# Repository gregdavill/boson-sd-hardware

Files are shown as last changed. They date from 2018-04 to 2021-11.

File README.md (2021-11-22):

# bosonFrameGrabber

	Project Stage: Basic MVP achieved

A Small FPGA based board. Designed to connect to a FLIR Boson Camera, and save images from the camera to a microSD card.

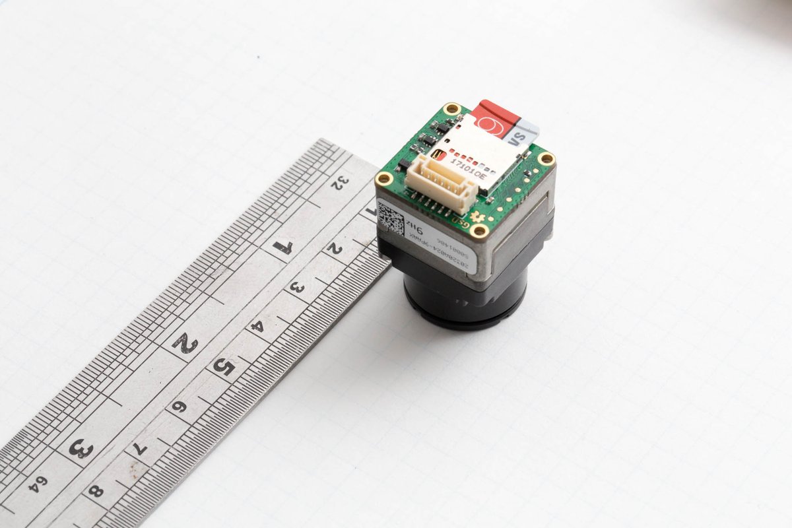
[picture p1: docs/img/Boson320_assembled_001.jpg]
Assembled Prototype

hw 1_02 is the latest functionaly hardware that fits just behind the back of the Boson. (Pictured Above)

## Project Status:
 + hw 1_01 working (reached limitations of FPGA)
 + hw 1_02 status
   + designed/assembled prototypes
   + Working on Firmware on a softcore riscv CPU. 
   + Basic capture system implmented in rtl.
   + Basic driver for SD card access using FatFS and SD-controller.

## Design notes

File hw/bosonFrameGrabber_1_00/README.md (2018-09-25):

# bosonFrameGrabber v1.00

	Board Status: Discarded
	Note: bad footprint for HyperRam.

A Small FPGA based board. Designed to connect to a FLIR Boson Camera, and save images from the camera to a microSD card.

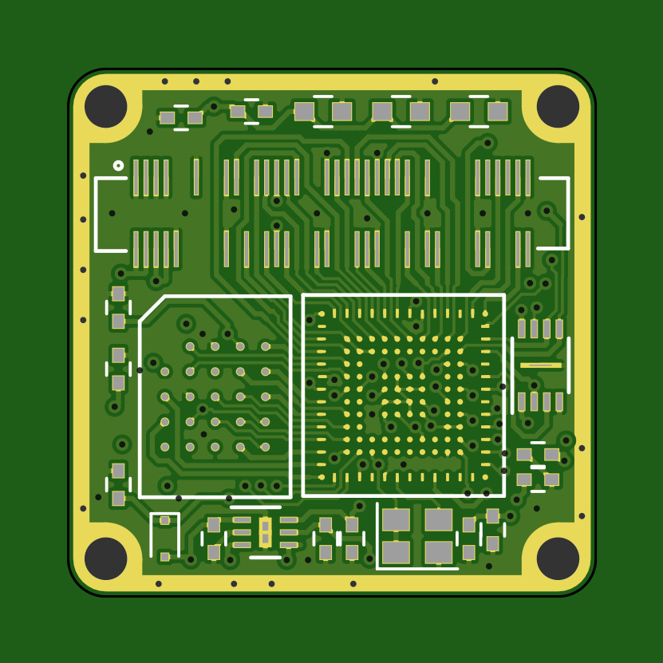
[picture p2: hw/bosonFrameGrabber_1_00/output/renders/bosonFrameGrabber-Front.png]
bosonFrameGrabber Front

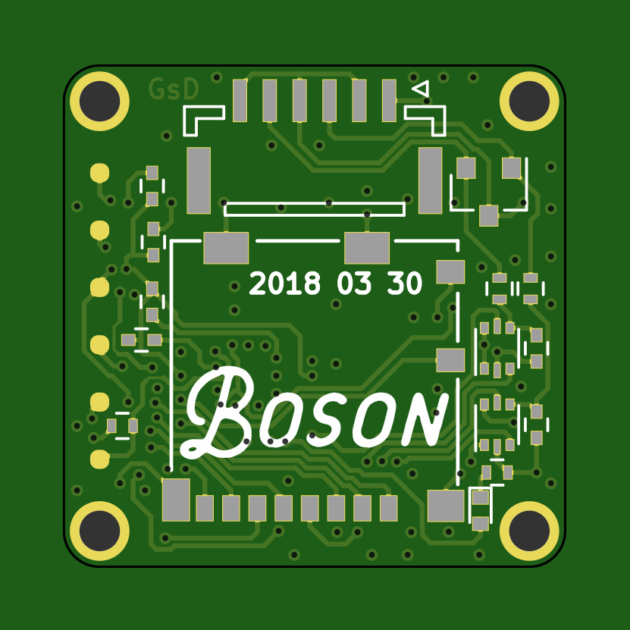
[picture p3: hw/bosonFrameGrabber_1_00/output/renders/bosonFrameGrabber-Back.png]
bosonFrameGrabber Back


## Hardware

* ICE40HX8K in csBGA132 package
* HyperRAM: high density, but low pin count.
* QSPI Memory
* MicroSD socket
* MEMs Oscillator
* JST GH SM06 locking Data/Power connector
* JTAG exposed via pogo pin pads.
* 2x 5V tolerant I/Os on connector
* 1x LED!

Prototype Limitations:
* Not quite enough decoupling, not too close to BGA pads.
* 3.3V only! (Integrated LDOs handle FPGA rails, but input power is connected directly to the Boson)
* Non-ideal BGA footprint to reduce prototyping costs.

## Goals

I have not worked with FPGAs in a project before, This project is a toy project of mine, to learn while having a clear goal. 

* Use Icestorm toolchain to develop for FPGA
* Deploy a risc-V softcore into the HX8K.
* Develop a HyperRAM interface.
* Develop/Integrate SDMMC IP. (Intially SD in SPI mode)
* Save Images from the CMOS camera interface to the SD card.

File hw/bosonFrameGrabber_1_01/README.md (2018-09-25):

# bosonFrameGrabber v1.01

	Board Status: Discarded
	Functionally this board worked, but the FPGA lacked the resources to easily enable a true SD mode interface.

A Small FPGA based board. Designed to connect to a FLIR Boson Camera, and save images from the camera to a microSD card.

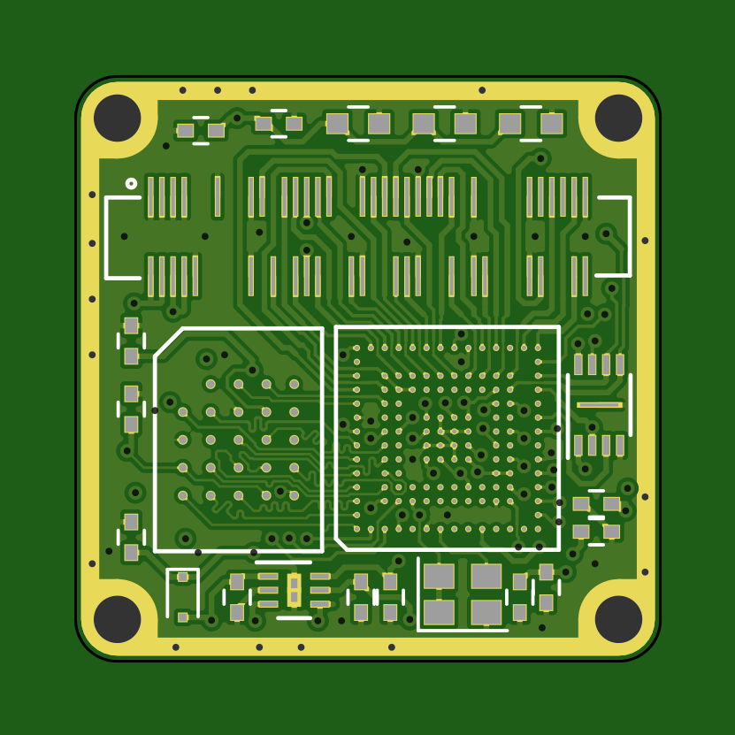
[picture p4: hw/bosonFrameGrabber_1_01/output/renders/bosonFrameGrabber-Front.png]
bosonFrameGrabber Front

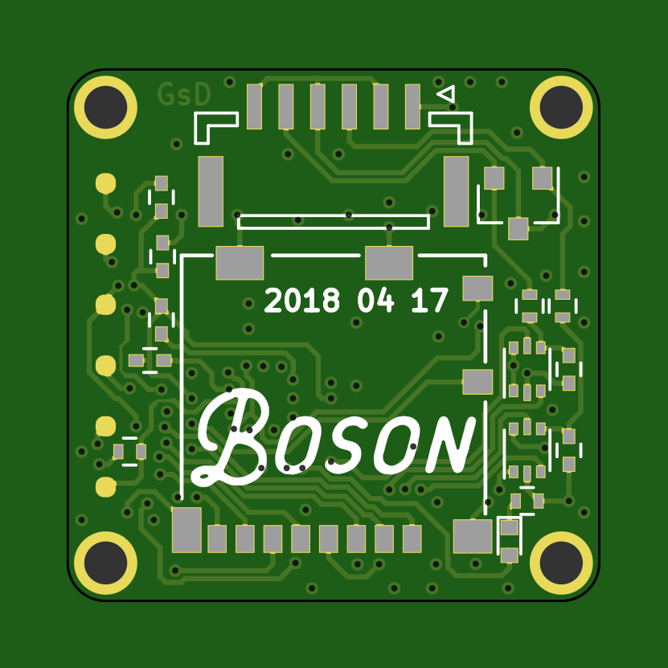
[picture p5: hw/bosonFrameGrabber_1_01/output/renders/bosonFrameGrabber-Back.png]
bosonFrameGrabber Back


## Hardware

* ICE40HX8K in csBGA132 package
* HyperRAM: high density, but low pin count.
* QSPI FLASH Memory
* MicroSD socket
* MEMs Oscillator
* JST GH SM06 locking Data/Power connector
* JTAG exposed via pogo pin pads.
* 2x 5V tolerant I/Os on connector
* 1x LED!

Prototype Limitations:
* Not quite enough decoupling, not too close to BGA pads.
* 3.3V only! (Integrated LDOs handle FPGA rails, but input power is connected directly to the Boson)

## Changes from 1_00
* Updated BGA footprint. Requires 3.5/3.5 (mil) track/space.
* Update HyperRam footprint to match datasheet.
* Length Match HyperRam Bus signals.

## Goals

I have not worked with FPGAs in a project before, This project is a toy project of mine, to learn while having a clear goal. 

* Use Icestorm toolchain to develop for FPGA
* Deploy a risc-V softcore into the HX8K.
* Develop a HyperRAM interface.
* Develop/Integrate SDMMC IP. (Intially SD in SPI mode)
* Save Images from the CMOS camera interface to the SD card.

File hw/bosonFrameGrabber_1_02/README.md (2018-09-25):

# bosonFrameGrabber v1.02

	Project Stage: Still in Development

A Small FPGA based board. Designed to connect to a FLIR Boson Camera, and save images from the camera to a microSD card.

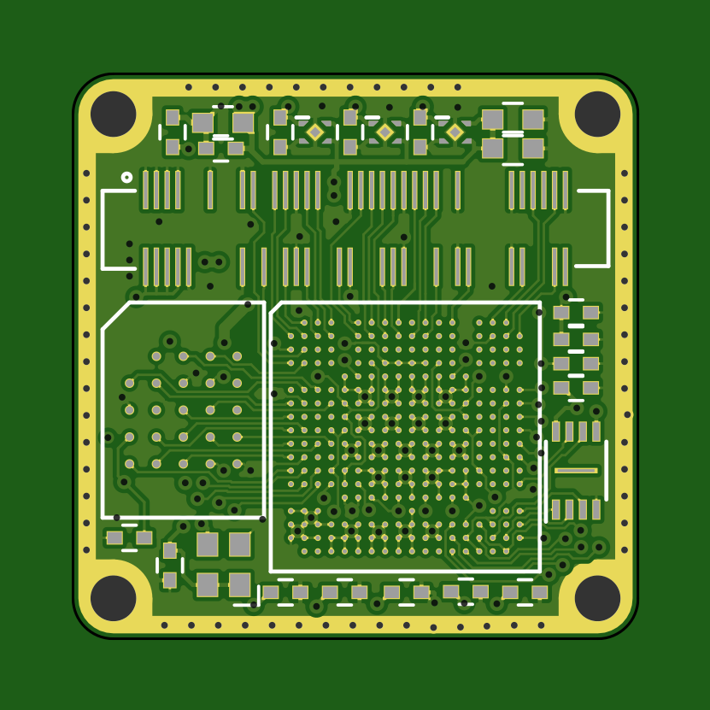
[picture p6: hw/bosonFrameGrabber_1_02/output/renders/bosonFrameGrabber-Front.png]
bosonFrameGrabber Front

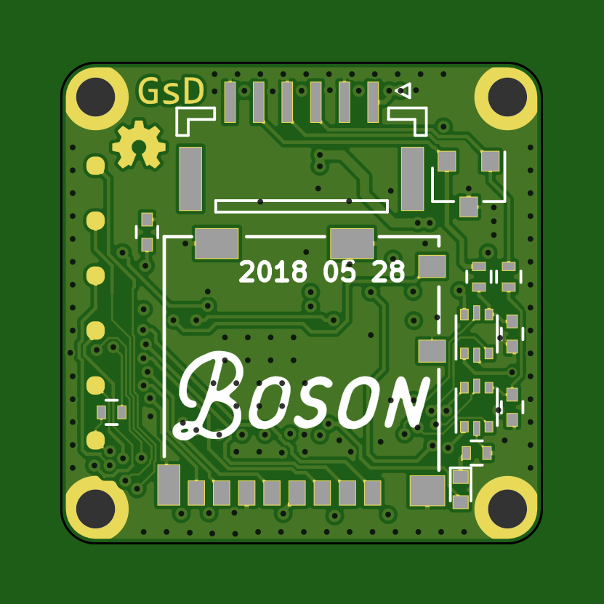
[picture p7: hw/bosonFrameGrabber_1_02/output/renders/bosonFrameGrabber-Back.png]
bosonFrameGrabber Back


## Hardware

* ECP5 in csBGA285 package
* 64Mb/128Mb HyperRAM
* 8Mb QSPI Memory
* MicroSD socket
* 24Mhz MEMs Oscillator
* JST GH SM06 locking Data/Power connector
* JTAG exposed via pogo pin pads.
* 2x 5V tolerant I/Os on connector
* 1x LED

Prototype Limitations:
* 3.3V only! (Integrated LDOs handle FPGA rails, but input power is connected directly to the Boson)

## Prototype

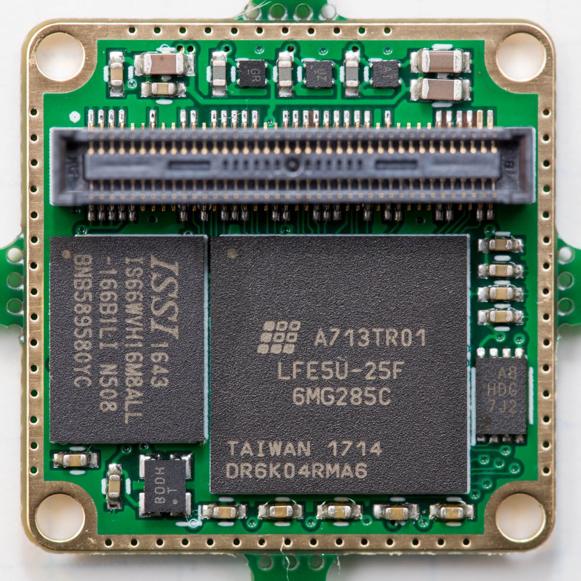
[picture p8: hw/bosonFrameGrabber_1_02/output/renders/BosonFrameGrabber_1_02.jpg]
bosonFrameGrabber Proto


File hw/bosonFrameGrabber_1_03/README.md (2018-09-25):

# bosonFrameGrabber 1_03

	Development BigBoard (Do not use! known errata)

Due to supply issues of the ECP5 in cs285 I developed this PCB to start work on firmware. Despite many errata the board was functional (after mods) and did aid in fw development.

## Errata
* 1V8 line shorted by a via (didn't run DRC)
* SysConfig pins are not correct for loading bitstream from SPI.
* Incorrect pins connected to QSPI.
* 3V3 not connected to backlinght DCDC

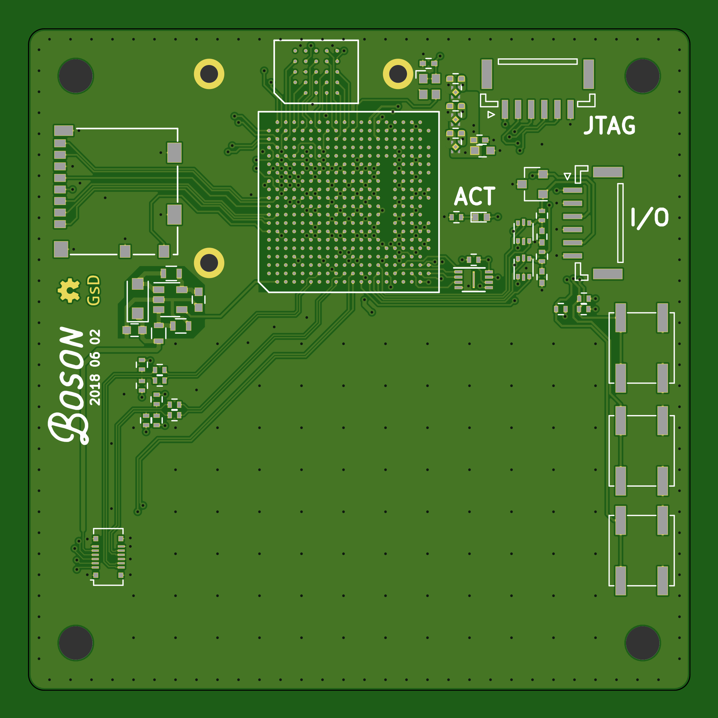
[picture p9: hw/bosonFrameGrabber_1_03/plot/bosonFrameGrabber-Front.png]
bosonFrameGrabber Front

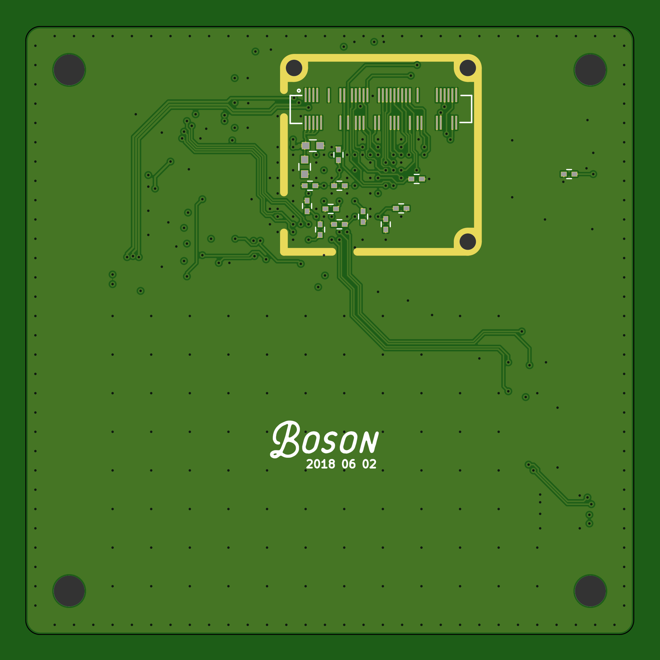
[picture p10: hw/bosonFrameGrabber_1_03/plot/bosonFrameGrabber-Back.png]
bosonFrameGrabber Back


## Hardware

* ECP5 
* 8MB/16MB HyperRAM: high density, low pin count.
* 1MB QSPI Memory (XSON 3x2 package)
* MicroSD socket
* MEMs Oscillator
* JST GH SM06 locking Data/Power connector
* JTAG on GH SM06
* 2x 5V tolerant I/Os on connector
* 1x LED
* 240x240 IPS LCD. (used on NANO v6, MIPI interface)

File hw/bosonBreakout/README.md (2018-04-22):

# bosonBreakout

	Project Stage: VERY Early Development
	!!! Note this design has an incorrect HyperRam footprint !!!

(Initially a project called: CrushedICE)

A FPGA based camera interface board. This PCB was developed before the bosonFrameGrabber, and has a vastly different architecture. It uses an ICE5LP4K, HyperRAM and a QSPI bridge to a SAMD51.

FPGA+RAM will act as a FIFO, connect to SAMD51 via QSPI. To read out a frame when required. SAMD51 has a SDMMC module so it handles the writing to an SD card. 

Filled with test headers to make it easy to connect to a Saleae Logic analyser.

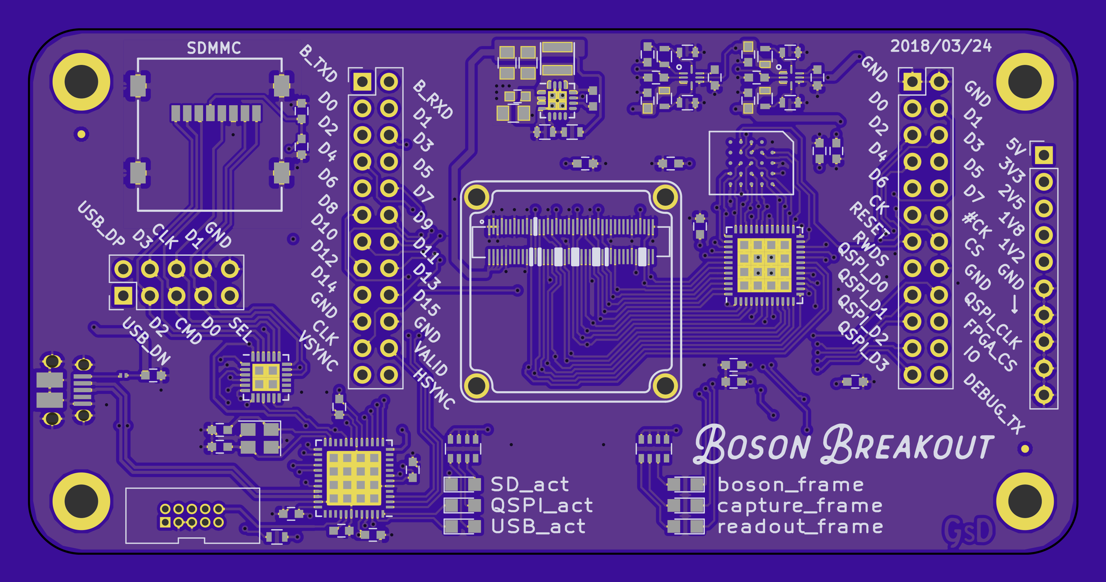
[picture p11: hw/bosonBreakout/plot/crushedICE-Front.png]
bosonFrameGrabber Front

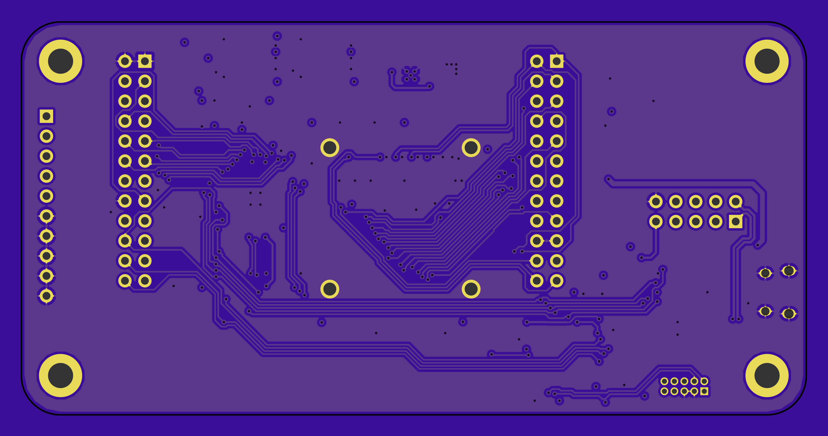
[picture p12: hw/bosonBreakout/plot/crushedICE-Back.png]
bosonFrameGrabber Back


## Hardware

* ICE5LP4K in QFN48 package
* HyperRAM: high density, but low pin count.
* QSPI Bus
* Microchip SAMD51
* MicroSD socket
* 16MHz Oscillator
* 6x LEDs!
* TOO MANY TEST POINTS!

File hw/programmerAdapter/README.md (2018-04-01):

# programmerAdapter

	Project Stage: Early Development

A simple adapter for Esden's ftdi universial Breakout board. <br>https://github.com/icebreaker-fpga/icebreaker/tree/master/hardware/ftdi-v1.0a 

## Design
Designed to suit the BosonFrameGrabber PCB. This design uses pogoPins to make connection and screws over the mounting holes into the Boson.

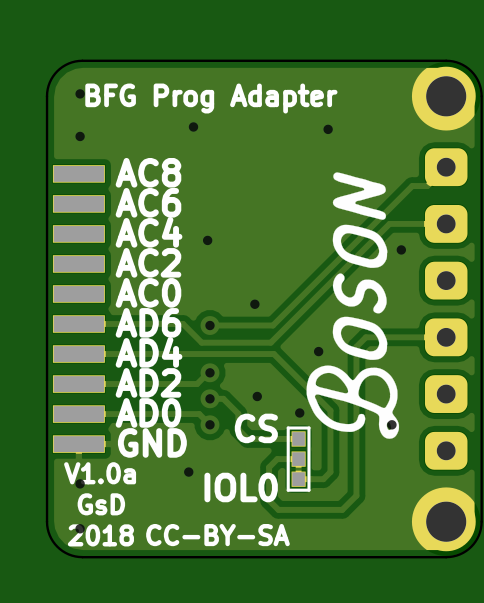
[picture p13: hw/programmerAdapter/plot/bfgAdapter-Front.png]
progammerAdapter Front

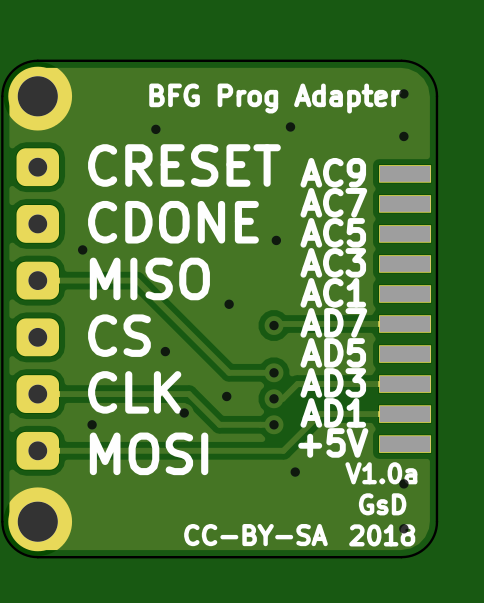
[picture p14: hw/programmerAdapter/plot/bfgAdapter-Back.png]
progammerAdapter Back


## Licence 

To match Esden's work this PCB is licenced: CC-BY-SA

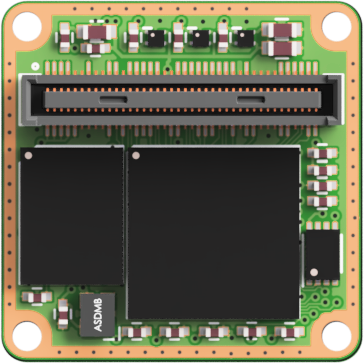
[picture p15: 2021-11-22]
docs/img/boson-r1d2-front.png

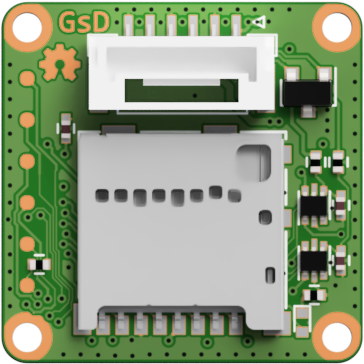
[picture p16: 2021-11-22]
docs/img/boson-r1d2-back.png

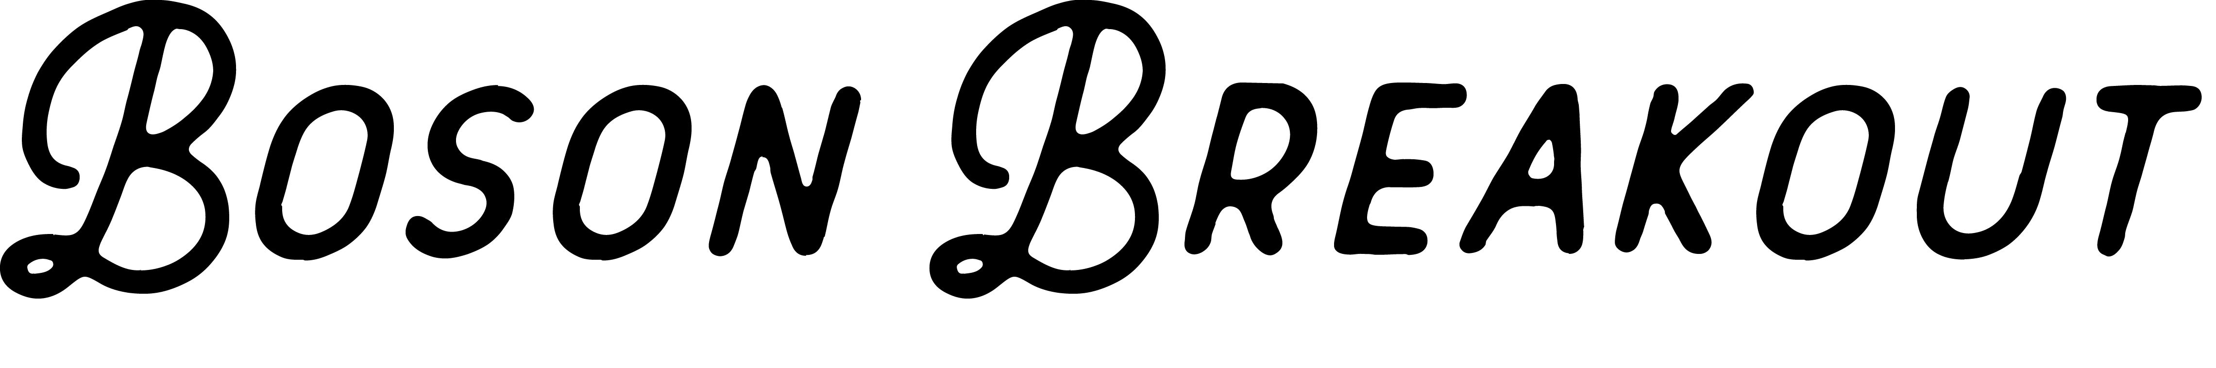
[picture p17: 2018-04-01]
hw/bosonBreakout/Name-01.png

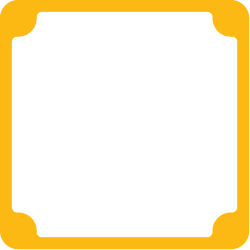
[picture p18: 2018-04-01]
hw/bosonBreakout/3d/boson_footprint.bmp

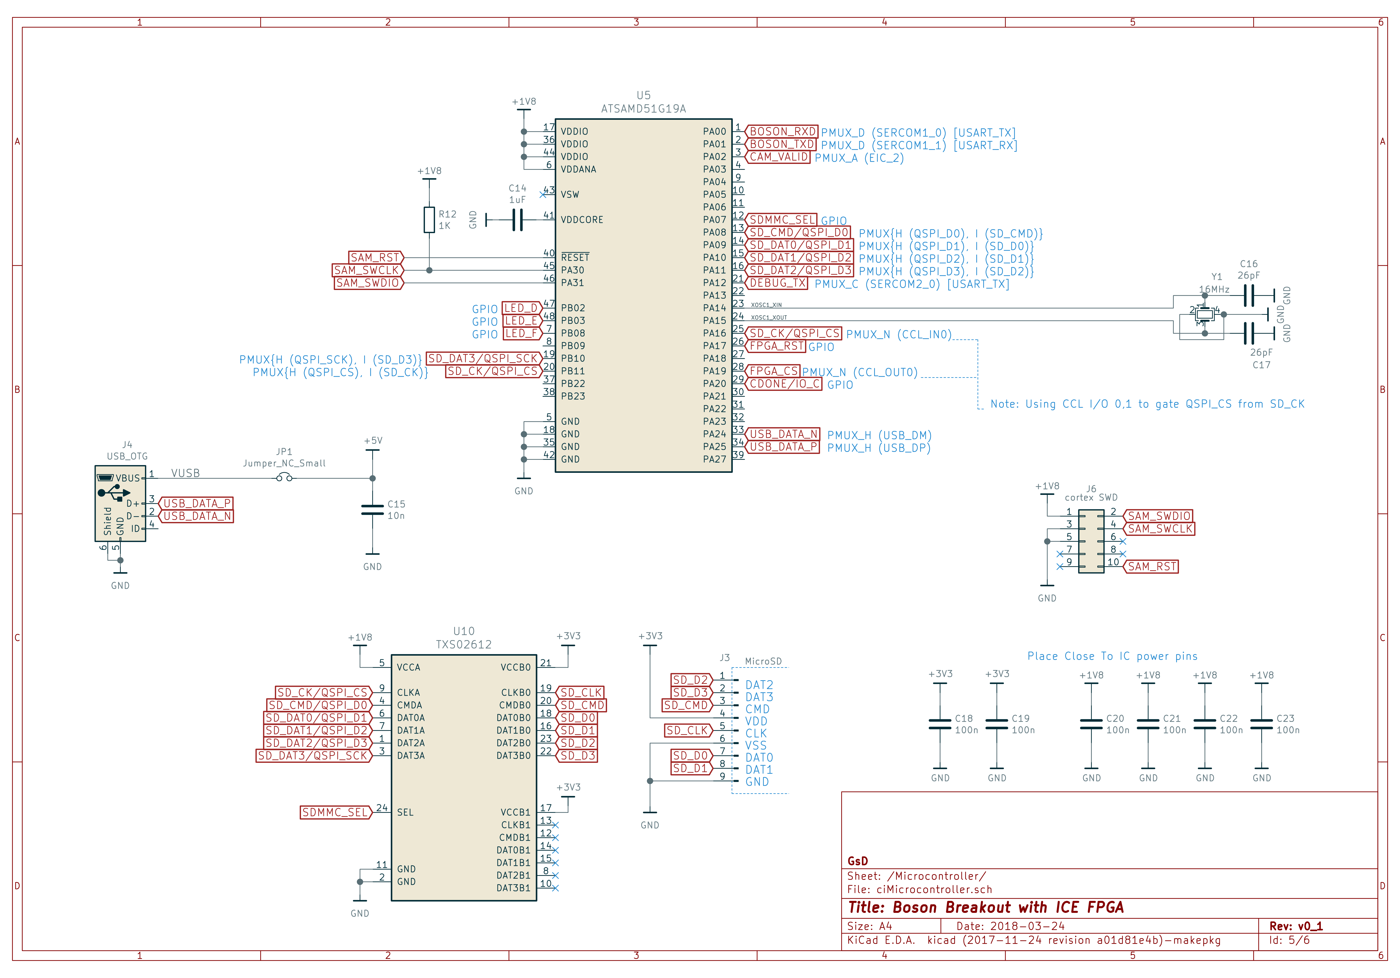
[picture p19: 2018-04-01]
hw/bosonBreakout/plot/ciMicrocontroller-Microcontroller-01.png

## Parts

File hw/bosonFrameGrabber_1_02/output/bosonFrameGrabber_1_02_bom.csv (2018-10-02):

Reference | Quantity | Value | Footprint | Datasheet | PN | SN-DK
C1 C2 | 2 | 100pF | Capacitors_SMD:C_0402 |  | C0402C101J3GACTU | 399-1022-1-ND
C3 C4 C8 | 3 | 1uF | Capacitors_SMD:C_0402 |  | CGB2A1X5R1E105K033BC | 445-13185-1-ND
C10 C11 C12 C14 C15 C16 C17 C18 C19 C20 C21 C22 C5 C9 | 14 | 100nF | Capacitors_SMD:C_0402 |  | CL05B104KP5NNNC | 1276-1002-1-ND
C13 C6 C7 | 3 | 10uF | Capacitors_SMD:C_0603 |  | C1608X5R1A106K080AC | 445-7486-1-ND
D1 | 1 | LED | LEDs:LED_0603 |  | APHHS1005SYCK | 754-1105-1-ND
D2 | 1 | D_TVS_x2_AAC | TO_SOT_Packages_SMD:SOT-23 | https://en.wikipedia.org/wiki/Transient-voltage-suppression_diode | PESD5V0U2BT,215 | 1727-3936-1-ND
J1 | 1 | JST GH Series | Connectors_JST:JST_GH_BM06B-GHS-TBT_06x1.25mm_Straight | ~ | BM06B-GHS-TBT(LF)(SN)(N) | 455-1582-1-ND
J4 | 1 | MicroSD | bosonFrameGrabber:1040310811 | ~ | 1040310811 | WM6357CT-ND
R1 R2 | 2 | 100R | Resistors_SMD:R_0402 |  | RT0402FRE07100RL | YAG3342CT-ND
R3 R4 | 2 | 10k | Resistors_SMD:R_0402 |  | ERA-2AED103X | P10KDECT-ND
U1 | 1 | TLV70725 | bosonFrameGrabber:X2SON |  | TLV70725PDQNT | 296-34993-1-ND
U3 | 1 | ECP5U25 |  |  | LFE5UM-25F-6MG285C | LFE5UM-25F-6MG285C-ND
U4 | 1 | S27KS0641 | bosonFrameGrabber:BGA_24 |  | S27KS0641DPBHI020 | 428-3858-ND
U5 | 1 | Boson |  |  | DF40HC(4.0)-80DS-0.4V(51) | H11919CT-ND
U6 | 1 | AT25SF081 | Housings_DFN_QFN:DFN-8-1EP_3x2mm_Pitch0.5mm |  | AT25SF081-MAHD-T | 1265-1275-1-ND
U2 U7 | 2 | SN74LVC1T45 | TO_SOT_Packages_SMD:SOT-666 |  | SN74LVC1T45DRLR | 296-20629-1-ND
U8 | 1 | TLV71718 | bosonFrameGrabber:X2SON |  | TLV71718PDQNR | 296-36775-1-ND
U9 | 1 | TLV73311 | bosonFrameGrabber:X2SON |  | TLV73311PDQNT | 296-38619-1-ND
X1 | 1 | ASDMB | Oscillators:Oscillator_SMD_SeikoEpson_SG210-4pin_2.5x2.0mm | http://www.abracon.com/Oscillators/ASV.pdf | SIT8008BI-71-18E-24.000000G | 1473-30509-1-ND

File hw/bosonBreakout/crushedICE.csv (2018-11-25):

Reference | Quantity | Value | Footprint | Datasheet | SN-DK | PN | Mfg
C1 | 1 | 10uF | Capacitors_SMD:C_0805 |  | 1276-2402-1-ND
C10 C11 C12 C14 C9 | 5 | 1uF | Capacitors_SMD:C_0603
C15 | 1 | 10n | Capacitors_SMD:C_0603
C16 C17 | 2 | 26pF | Capacitors_SMD:C_0603 |  | 1276-2229-1-ND
C13 C18 C19 C2 C20 C21 C22 C23 C24 C25 C26 C27 C28 C29 C3 C30 C31 | 17 | 100n | Capacitors_SMD:C_0603
C4 C5 C6 | 3 | 22nF | Capacitors_SMD:C_0603 |  | 1276-1104-1-ND
C7 C8 | 2 | 22uF | Capacitors_SMD:C_0805 |  | 490-1719-1-ND
D1 D2 D3 D4 D5 D6 | 6 | led green | LEDs:LED_0805
J1 J2 | 2 | Conn_02x12_Odd_Even
J3 | 1 | MicroSD | lib:SD_holder_472190001 |  | WM6698CT-ND
J4 | 1 | USB_OTG | Connectors:USB_Micro-B_10103594-0001LF |  | 609-4618-1-ND
J5 | 1 | Conn_02x05_Odd_Even | Pin_Headers:Pin_Header_Straight_2x05_Pitch2.54mm
J6 | 1 | cortex SWD | lib:CORTEX_SWD
J7 | 1 | Conn_01x10 | Pin_Headers:Pin_Header_Straight_1x10_Pitch2.54mm
JP1 | 1 | Jumper_NC_Small | Resistors_SMD:R_0201_NoSilk
L1 | 1 | 4.7uH | Inductors:Inductor_Taiyo-Yuden_MD-3030 |  | 490-15977-1-ND | LQH3NPZ4R7MMEL | Murata Electronics North America
R10 | 1 | 23K | Resistors_SMD:R_0603 |  | P23.2KHCT-ND
R12 | 1 | 1K | Resistors_SMD:R_0603
R2 | 1 | 2.0K | Resistors_SMD:R_0603 |  | P2.00KHCT-ND
R4 | 1 | 15K | Resistors_SMD:R_0603 |  | P15.0KHCT-ND
R6 | 1 | 17.8K | Resistors_SMD:R_0603 |  | P17.8KHCT-ND
R11 R3 R5 R7 R9 | 5 | 10K | Resistors_SMD:R_0603 |  | P10.0KHCT-ND
R8 | 1 | 8.0K | Resistors_SMD:R_0603 |  | P8.06KHCT-ND
RN1 RN2 | 2 | R_Pack04 | Resistors_SMD:R_Array_Convex_4x0603
U1 | 1 | ICE5LP4K-SG48 | Housings_DFN_QFN:QFN-48-1EP_7x7mm_Pitch0.5mm |  | 220-2068-1-ND
U10 | 1 | TXS02612 | Housings_DFN_QFN:QFN-24-1EP_4x4mm_Pitch0.5mm |  | 296-23869-1-ND
U2 | 1 | S27KS0641 | lib:BGA_24
U4 | 1 | Boson | lib:DF40_80Pin |  | H11919CT-ND
U5 | 1 | ATSAMD51G19A | Housings_DFN_QFN:QFN-48-1EP_7x7mm_Pitch0.5mm |  | ATSAMD51G19A-MU-ND
U6 U7 | 2 | SC560A | lib:MLPQ-UT8 |  | SC560CULCT-ND
U8 | 1 | TS30011 | Housings_DFN_QFN:QFN-16-1EP_3x3mm_Pitch0.5mm_ThermalVias |  | TS30011-M033QFNRCT-ND | TS30011-M033QFNR | Semtech Corporation
Y1 | 1 | 16MHz | Crystals:Crystal_SMD_3225-4pin_3.2x2.5mm |  | SER4046CT-ND

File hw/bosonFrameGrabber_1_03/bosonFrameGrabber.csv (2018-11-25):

Reference | Quantity | Value | Footprint | Datasheet | SN-DK | PN | Mfg
C1 C2 | 2 | 100pF | Capacitors_SMD:C_0402 |  | 399-1022-1-ND | C0402C101J3GACTU
C23 C24 | 2 | 1uF | Capacitors_SMD:C_0603 |  | 445-12539-1-ND | CGA3E1X7R1C105K080AC
C3 C4 C8 | 3 | 1uF | Capacitors_SMD:C_0402 |  | 445-13185-1-ND | CGB2A1X5R1E105K033BC
C10 C11 C12 C14 C15 C16 C17 C18 C19 C20 C21 C22 C5 C9 | 14 | 100nF | Capacitors_SMD:C_0402 |  | 1276-1002-1-ND | CL05B104KP5NNNC
C13 C6 C7 | 3 | 10uF | Capacitors_SMD:C_0603 |  | 445-7486-1-ND | C1608X5R1A106K080AC
D1 | 1 | LED | LEDs:LED_0603 |  | 754-1105-1-ND | APHHS1005SYCK
D2 | 1 | D_TVS_x2_AAC | TO_SOT_Packages_SMD:SOT-23 | https://en.wikipedia.org/wiki/Transient-voltage-suppression_diode | 1727-3936-1-ND | PESD5V0U2BT,215
D3 | 1 | D_Schottky_ALT | Diodes_SMD:D_SOD-123F |  | 1N5819HW1-7-FDICT-ND
J1 J2 | 2 | JST GH Series | Connectors_JST:JST_GH_BM06B-GHS-TBT_06x1.25mm_Straight |  | 455-1582-1-ND | BM06B-GHS-TBT(LF)(SN)(N)
J4 | 1 | MicroSD | bosonFrameGrabber:1040310811 |  | WM6357CT-ND | 1040310811
J5 | 1 | SlimStack_12P |  |  | WM4662CT-ND | 5035481220
L1 | 1 | L | Inductors_SMD:L_0603 |  | 445-3608-1-ND
R1 R2 | 2 | 100R | Resistors_SMD:R_0402 |  | YAG3342CT-ND | RT0402FRE07100RL
R10 R14 R15 R9 | 4 | 47R | Resistors_SMD:R_0402 |  | YAG3491CT-ND | AC0402FR-0747RL
R11 | 1 | 1K | Resistors_SMD:R_0402 |  | P1.0KJCT-ND | ERJ-2GEJ102X
R12 R13 R7 R8 | 4 | 220R | Resistors_SMD:R_0402 |  | YAG3456CT-ND | AC0402FR-07220RL
R16 R17 R18 R3 R4 | 5 | 10k | Resistors_SMD:R_0402 |  | P10KDECT-ND | ERA-2AED103X
R5 | 1 | 56k | Resistors_SMD:R_0603 |  | RR08P56.0KDCT-ND | RR0816P-563-D
R6 | 1 | 5.1K | Resistors_SMD:R_0603 |  | RR08P5.1KDCT-ND | RR0816P-512-D
SW1 SW2 SW3 | 3 | SW_Push | Buttons_Switches_SMD:SW_SPST_EVQP0 |  | P12244SCT-ND | EVQ-P1K05M
U1 U8 U9 | 3 | TLV733P | bosonFrameGrabber:X2SON |  | 296-38493-1-ND | TLV73325PDQNT | Texas Instruments
U10 | 1 | AP3012 | TO_SOT_Packages_SMD:SOT-23-5 |  | AP3012KTR-E1DICT-ND | AP3012KTR-E1
U3 | 1 | ECP5U25 |  |  | 220-2052-ND | LFE5U-25F-6BG381I | Lattice
U4 | 1 | S27KS0641 | bosonFrameGrabber:BGA_24 |  | 428-3858-ND | S27KS0641DPBHI020
U5 | 1 | Boson |  |  | H11919CT-ND | DF40HC(4.0)-80DS-0.4V(51)
U6 | 1 | AT25SF081 | Housings_DFN_QFN:DFN-8-1EP_3x2mm_Pitch0.5mm |  | 1265-1275-1-ND | AT25SF081-MAHD-T
U2 U7 | 2 | SN74LVC1T45 | TO_SOT_Packages_SMD:SOT-666 |  | 296-20629-1-ND | SN74LVC1T45DRLR | Texas Instruments
X1 | 1 | ASDMB | Oscillators:Oscillator_SMD_SeikoEpson_SG210-4pin_2.5x2.0mm | http://www.abracon.com/Oscillators/ASV.pdf | 1473-30509-1-ND | SIT8008BI-71-18E-24.000000G

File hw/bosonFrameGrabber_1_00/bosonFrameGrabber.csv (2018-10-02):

Reference | Quantity | Value | Footprint | Datasheet | PN | SN-DK | SN-MO
C1 C2 | 2 | 100pF | Capacitors_SMD:C_0402 |  | C0402C101J3GACTU | 399-1022-1-ND
C10 C11 C12 C14 C16 C17 C19 C20 C21 C22 C23 C5 C8 C9 | 14 | 100n | Capacitors_SMD:C_0402 |  | CL05B104KP5NNNC | 1276-1002-1-ND
C3 C4 | 2 | 1uF | Capacitors_SMD:C_0402 |  | CGB2A1X5R1E105K033BC | 445-13185-1-ND
C13 C6 C7 | 3 | 10uF | Capacitors_SMD:C_0603 |  | C1608X5R1A106K080AC | 445-7486-1-ND
D1 | 1 | LED | LEDs:LED_0603 |  | LTST-C191KGKT | 160-1446-1-ND
D2 | 1 | D_TVS_x2_AAC | TO_SOT_Packages_SMD:SOT-23 | https://en.wikipedia.org/wiki/Transient-voltage-suppression_diode | PESD5V0U2BT,215 | 1727-3936-1-ND
D3 | 1 | D_ALT | Diodes_SMD:D_SC-80 |  | 1N4148X-TP | 1N4148XTPMSCT-ND
J1 | 1 | JST GH Series | Connectors_JST:JST_GH_BM06B-GHS-TBT_06x1.25mm_Straight |  | BM05B-GHS-TBT(LF)(SN)(N) | 455-1581-1-ND
J4 | 1 | MicroSD | bosonFrameGrabber:1040310811 |  | 1040310811 | WM6357CT-ND
R1 R2 | 2 | 100R | Resistors_SMD:R_0402 |  | RT0402FRE07100RL | YAG3342CT-ND
R3 | 1 | 470R | Resistors_SMD:R_0402 |  | RMCF0402JT470R | RMCF0402JT470RCT-ND
R4 | 1 | 10k | Resistors_SMD:R_0402 |  | ERA-2AED103X | P10KDECT-ND
U1 | 1 | MIC5370 |  |  | MIC5370-G4YMT-TR | 576-3329-1-ND | 998-MIC5370-G4YMTTR
U3 | 1 | ICE40HX8K-CB132 | bosonFrameGrabber:csBGA_132 |  | ICE40HX8K-CB132 | 220-1577-ND
U4 | 1 | S27KS0641 | bosonFrameGrabber:BGA_24 |  | S27KS0641DPBHI020 | 428-3858-ND
U5 | 1 | Boson |  |  | DF40HC(4.0)-80DS-0.4V(51) | H11919CT-ND
U6 | 1 | AT25SF081 | Housings_DFN_QFN:DFN-8-1EP_3x2mm_Pitch0.5mm |  | AT25SF081-MAHD-T | 1265-1275-1-ND
U2 U7 | 2 | SN74LVC1T45 | TO_SOT_Packages_SMD:SOT-666 |  | SN74LVC1T45DRLR | 296-20629-1-ND
X1 | 1 | ASDMB | Oscillators:Oscillator_SMD_SeikoEpson_SG210-4pin_2.5x2.0mm | http://www.abracon.com/Oscillators/ASV.pdf | ASDMB-24.000MHZ-LC-T | 535-11728-1-ND

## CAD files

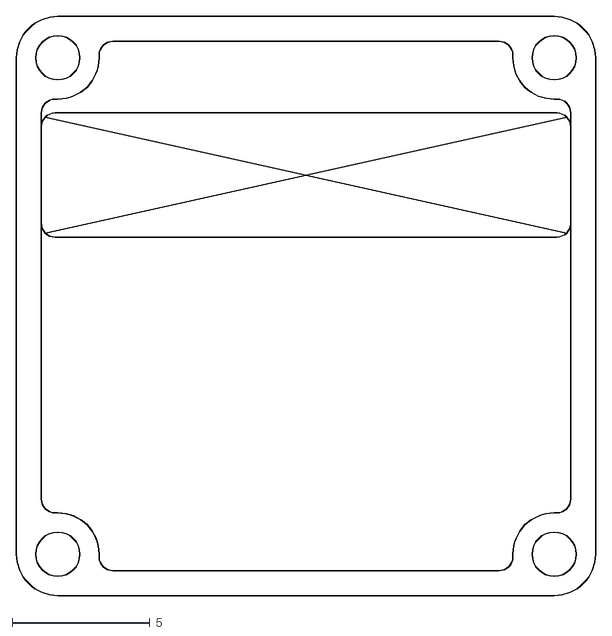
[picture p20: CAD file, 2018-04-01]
hw/bosonBreakout/3d/Boson_frame.dxf
21.0 x 21.0

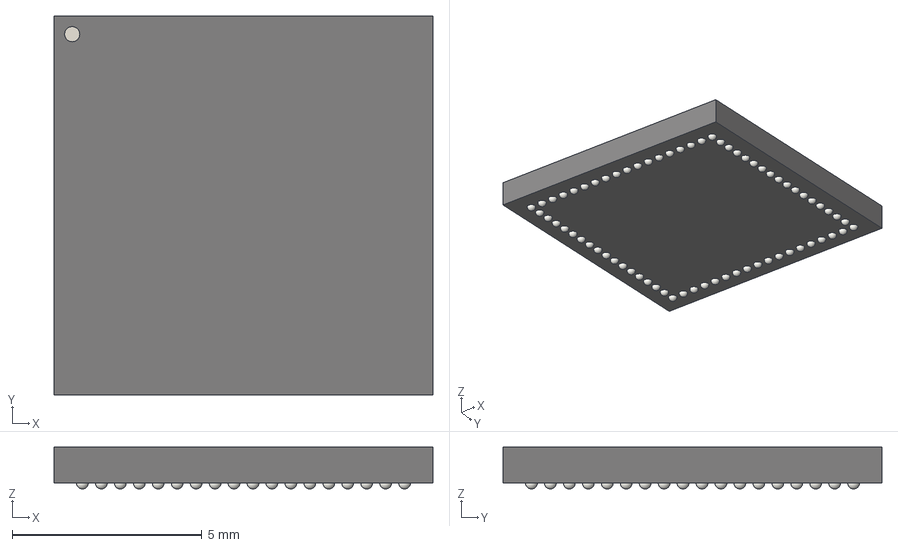
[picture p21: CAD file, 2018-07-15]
hw/bosonFrameGrabber_1_02/3d/csBGA285.step
10.0 x 10.0 x 1.11 mm

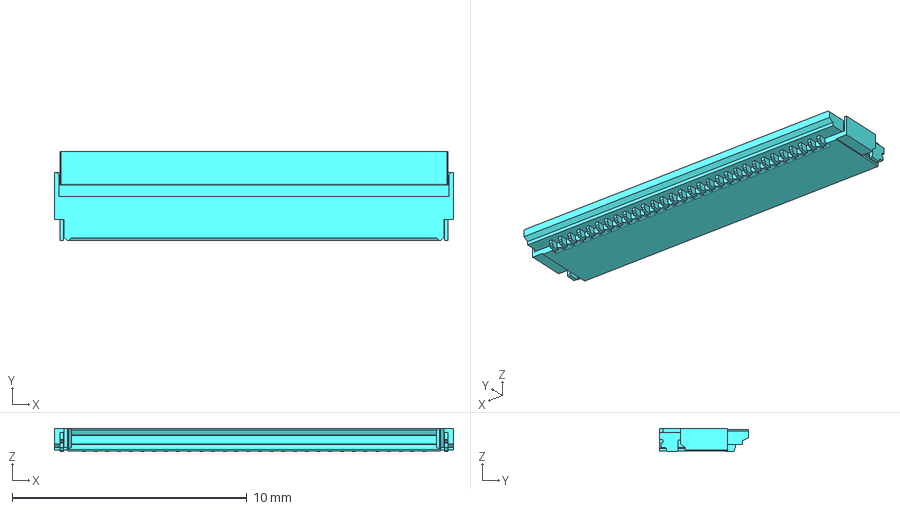
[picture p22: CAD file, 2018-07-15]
hw/bosonFrameGrabber_1_03/3d/FH34SRJ-30S-0.5SH.stp
17.0 x 3.80 x 1.00 mm

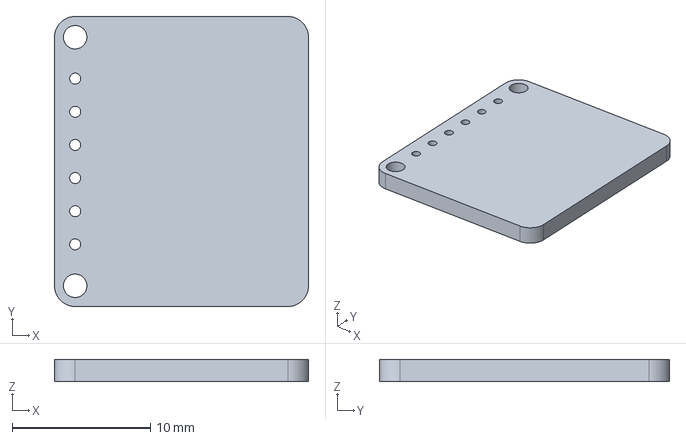
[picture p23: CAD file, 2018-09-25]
hw/programmerAdapter/bfgAdapter.stp
18.4 x 21.0 x 1.60 mm

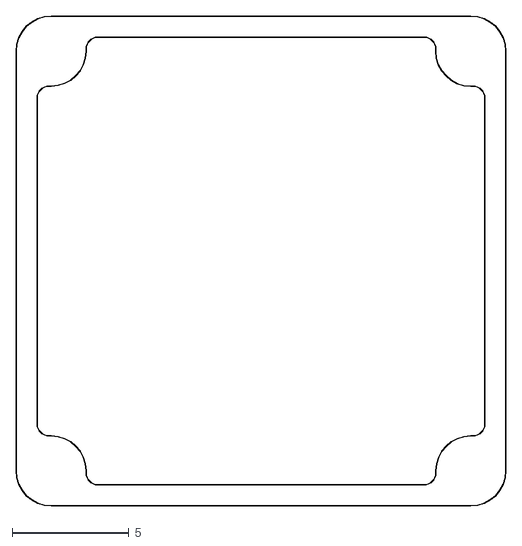
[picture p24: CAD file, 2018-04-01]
hw/bosonBreakout/3d/boson_footprint.dxf
21.0 x 21.0

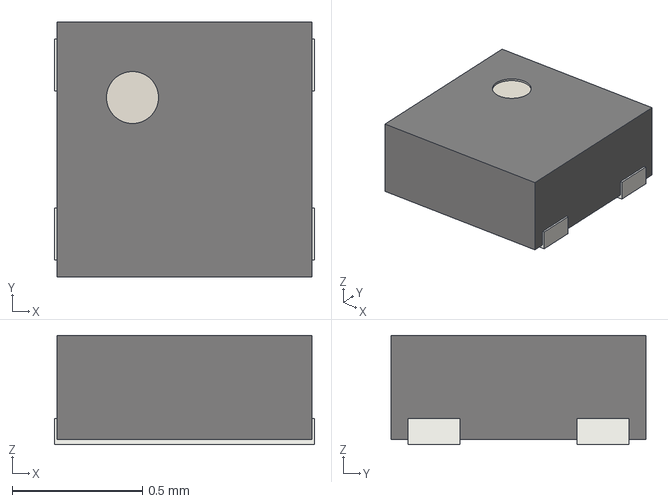
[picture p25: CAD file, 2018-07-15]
hw/bosonFrameGrabber_1_02/3d/xson-4.step
1.00 x 0.98 x 0.42 mm

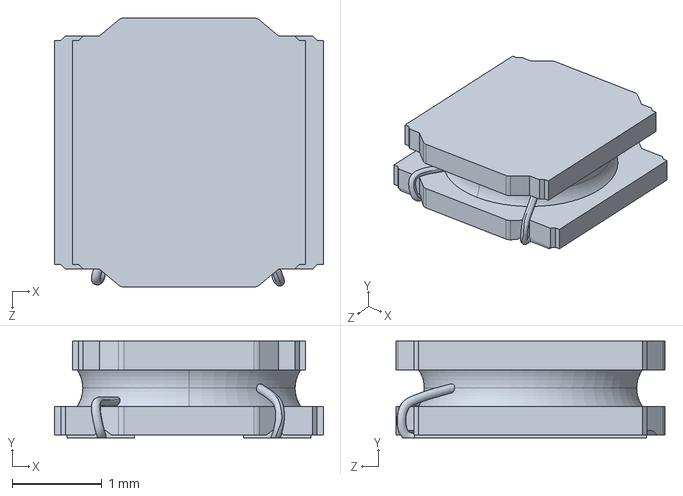
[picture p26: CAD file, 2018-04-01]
hw/bosonBreakout/3d/ASPI-3012S.STEP
3.00 x 1.08 x 3.00 mm

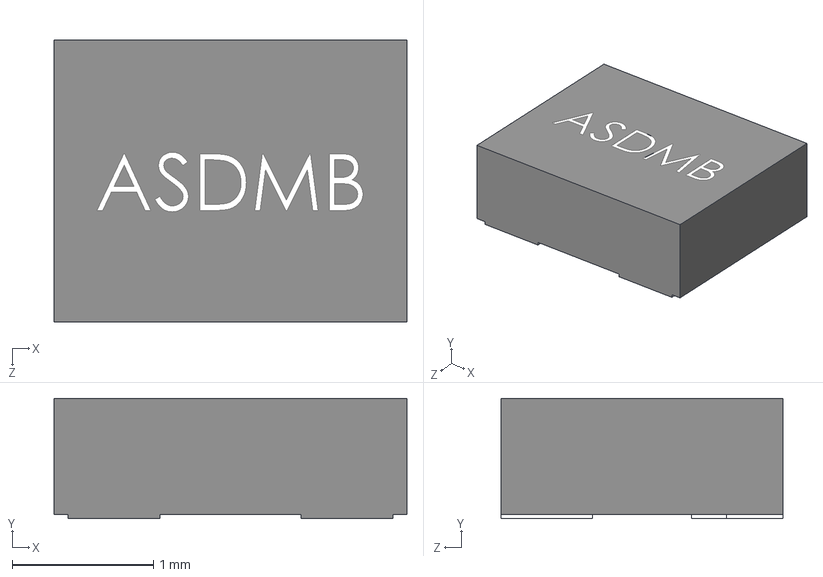
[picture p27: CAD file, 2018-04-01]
hw/bosonFrameGrabber_1_02/3d/ASDMB.STEP
2.50 x 0.85 x 2.00 mm

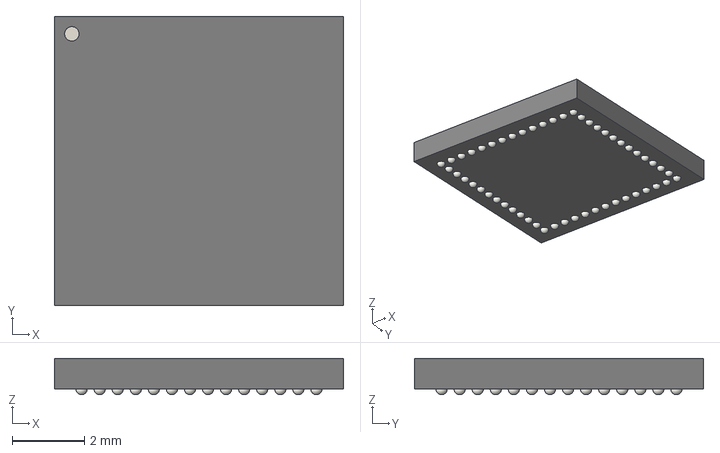
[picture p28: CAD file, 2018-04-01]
hw/bosonFrameGrabber_1_02/3d/csBGA_132.step
8.00 x 8.00 x 1.01 mm

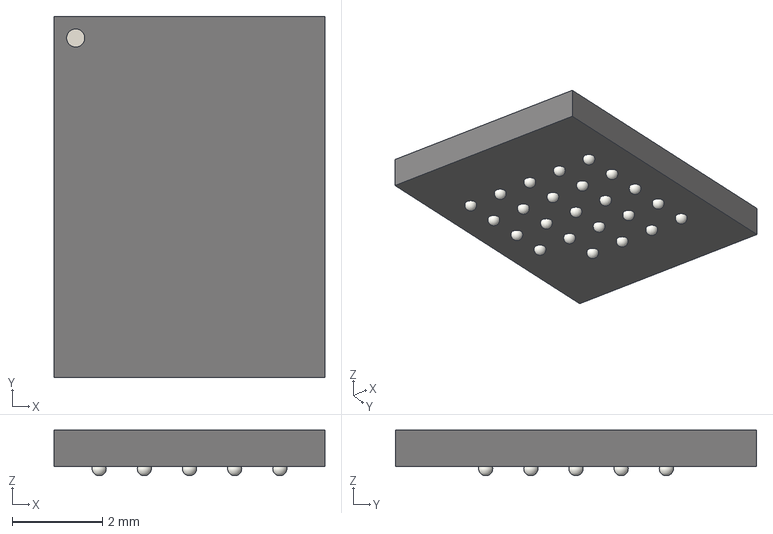
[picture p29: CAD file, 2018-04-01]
hw/bosonFrameGrabber_1_03/3d/FBGA_24.step
6.00 x 8.00 x 1.01 mm

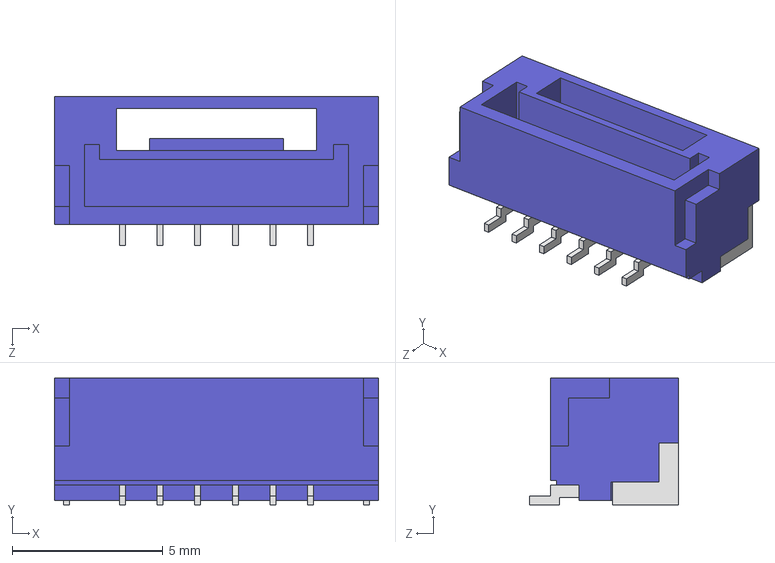
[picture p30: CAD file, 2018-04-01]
hw/bosonFrameGrabber_1_03/3d/BM06B-GHS-TBT.STEP
10.8 x 4.20 x 4.95 mm

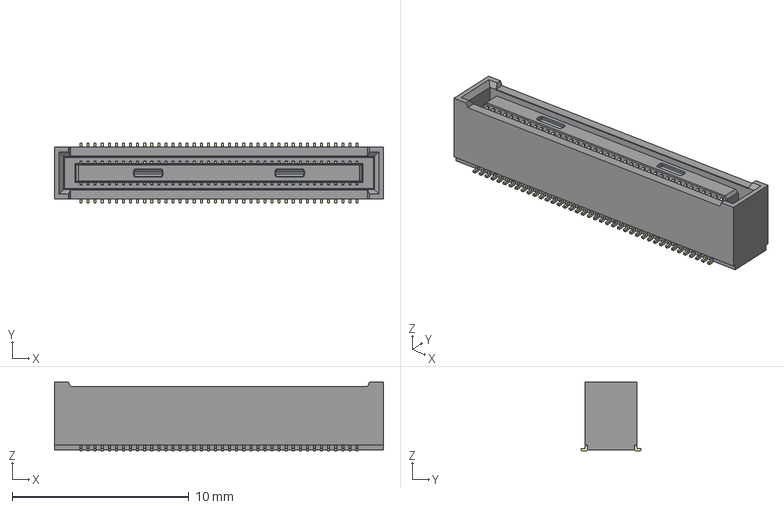
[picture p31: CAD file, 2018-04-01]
hw/bosonFrameGrabber_1_03/3d/DF40HC(4.0)-80DS.step
18.6 x 3.38 x 3.90 mm

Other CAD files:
hw/bosonFrameGrabber_1_02/3d/GHBM06.step
hw/bosonFrameGrabber_1_02/3d/1040310811.stp
hw/bosonFrameGrabber_1_02/3d/DF40HC(4.0)-80DS.stp
hw/bosonFrameGrabber_1_02/3d/MicroSD.step
hw/bosonFrameGrabber_1_03/3d/1040310811.stp
hw/bosonFrameGrabber_1_03/3d/5035481220.stp
hw/bosonFrameGrabber_1_03/3d/DF40HC(4.0)-80DS.stp
hw/bosonFrameGrabber_1_03/3d/GHBM06.step
hw/bosonFrameGrabber_1_03/3d/MicroSD.step
hw/bosonFrameGrabber_1_03/3d/s10051922_3010elf.stp

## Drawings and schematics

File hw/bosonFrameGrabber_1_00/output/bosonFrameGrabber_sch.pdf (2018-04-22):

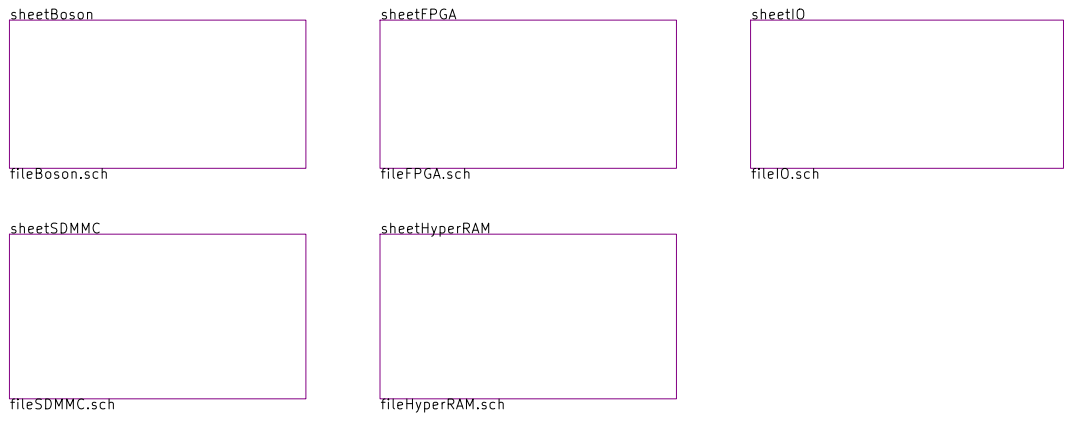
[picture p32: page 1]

Id: 1/6 Title: File: bosonFrameGrabber.sch Sheet: /

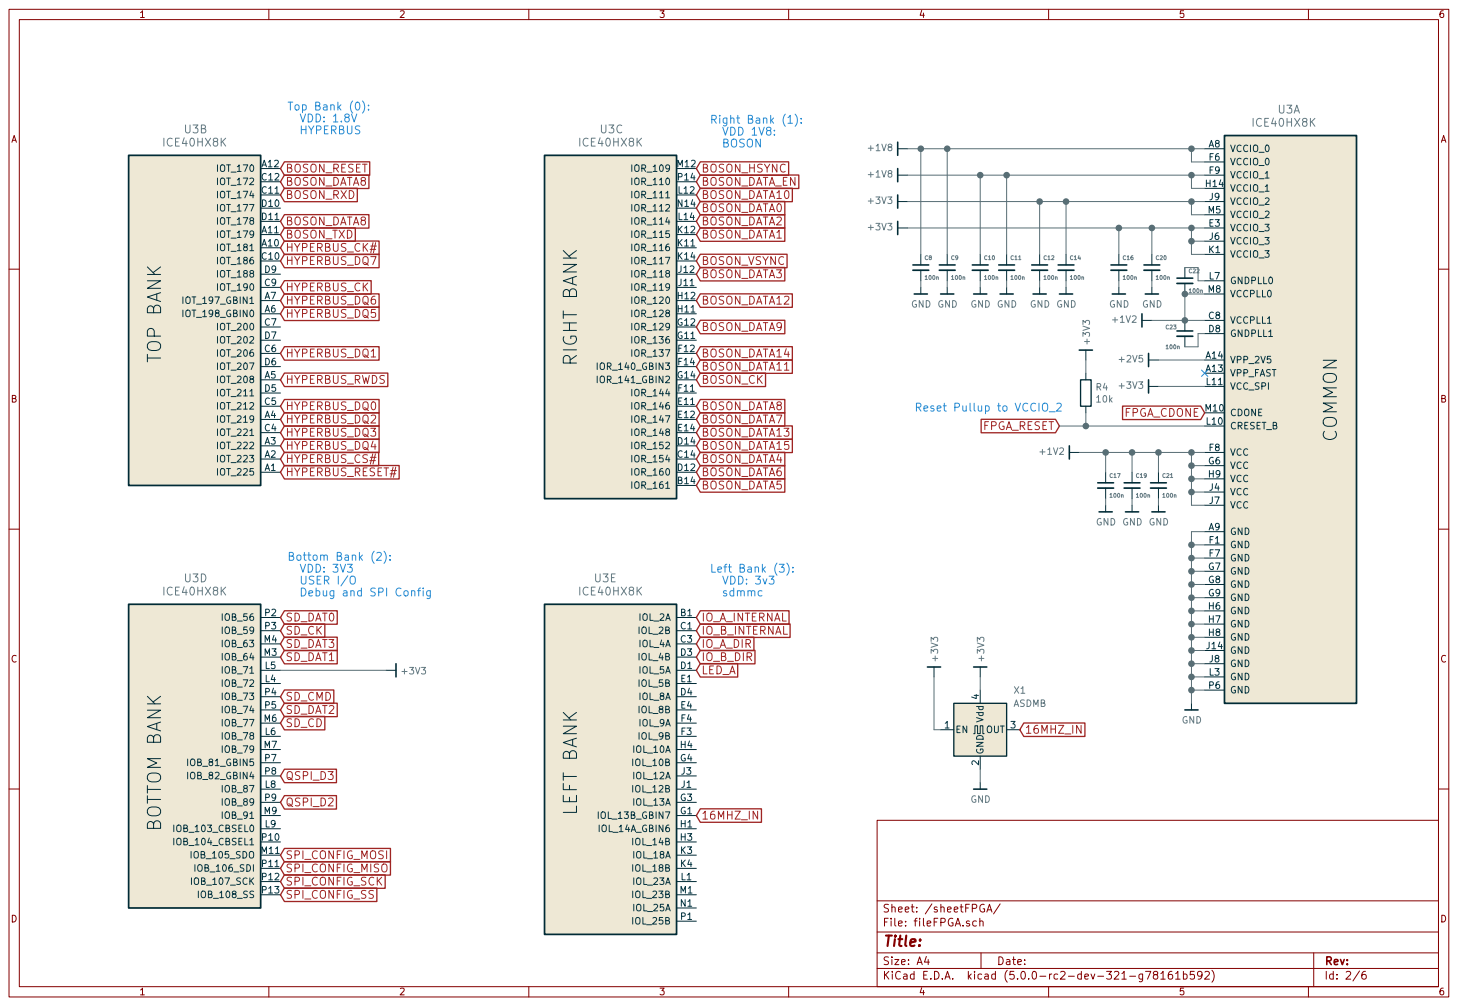
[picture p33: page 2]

Bottom Bank (2):
VDD: 3V3
USER I/O
Debug and SPI Config

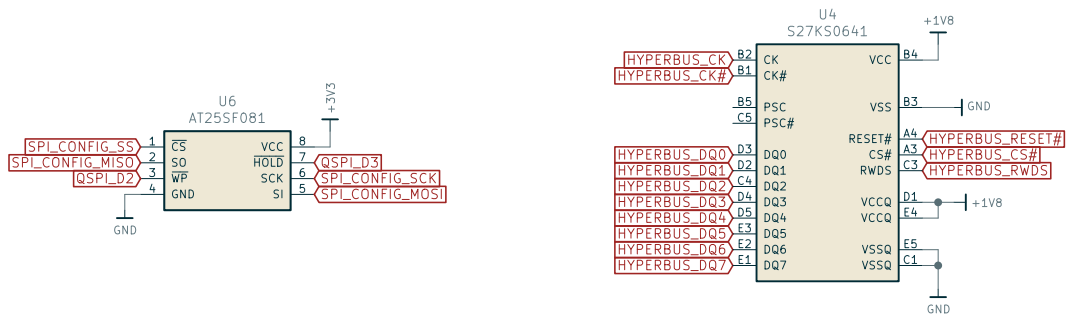
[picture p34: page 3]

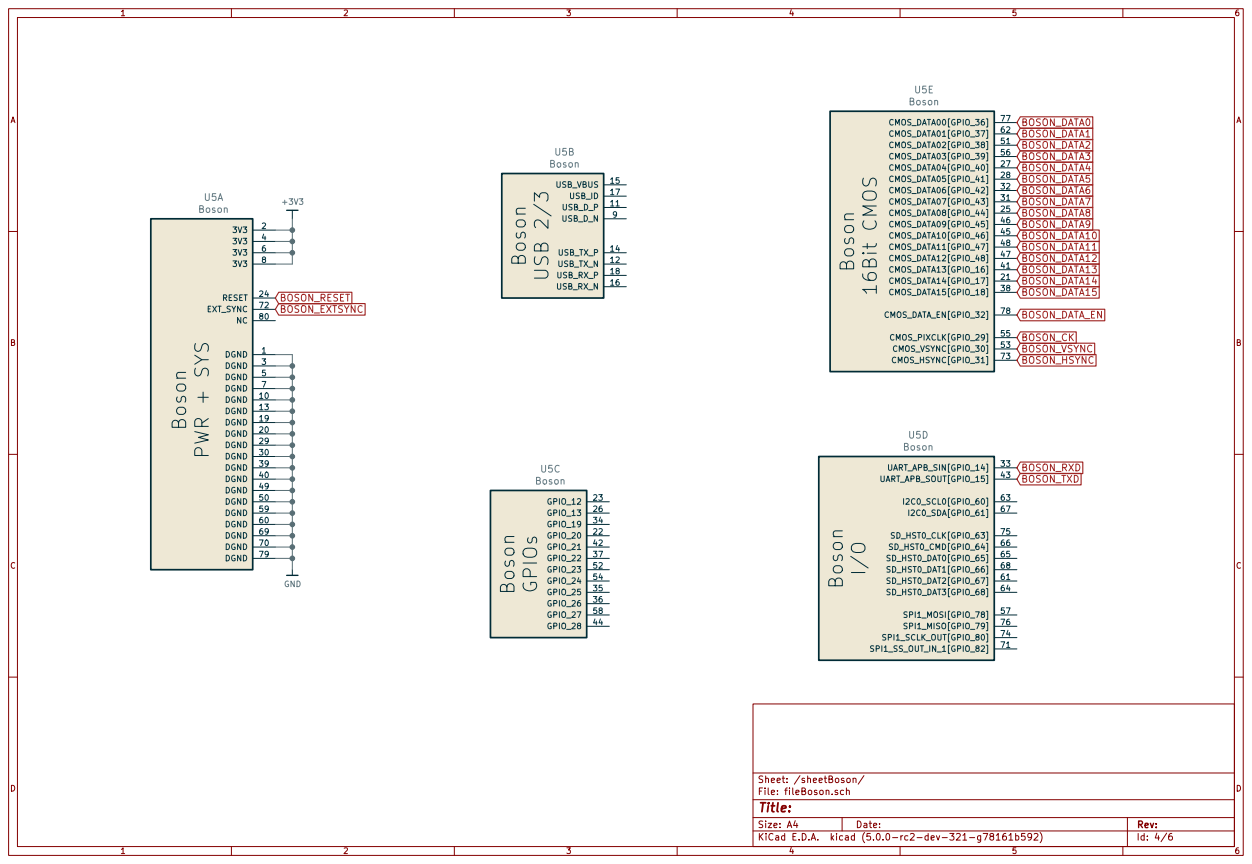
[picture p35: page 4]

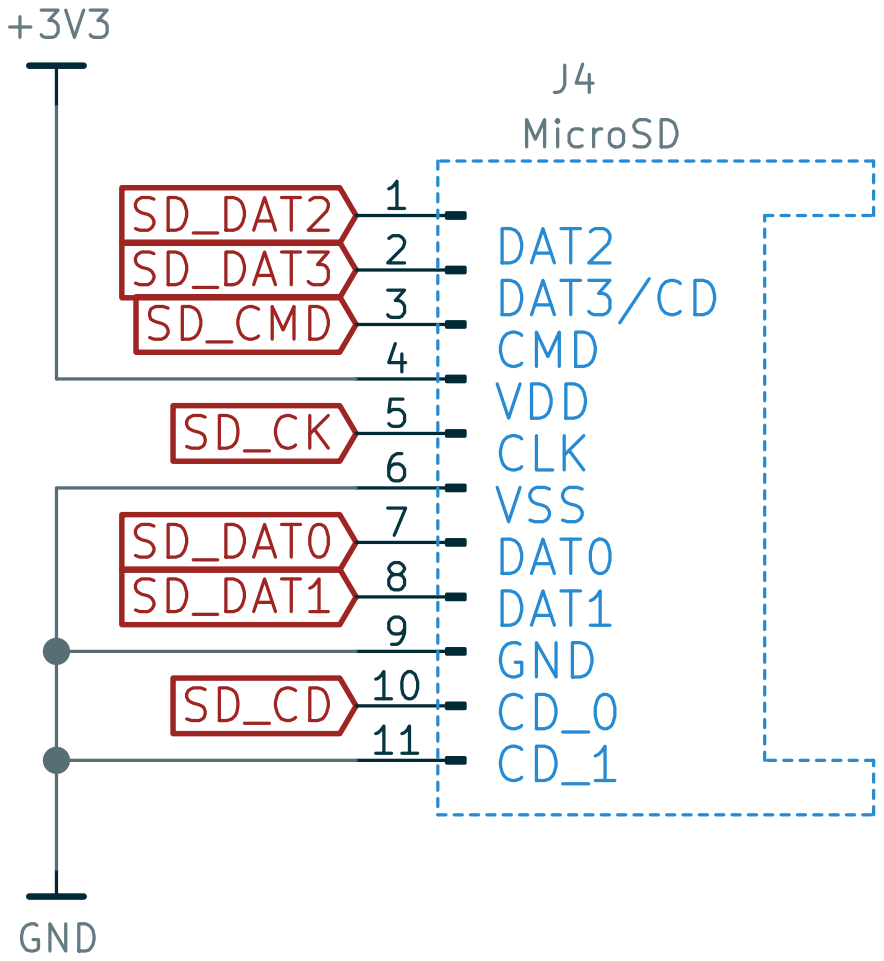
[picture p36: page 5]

Id: 5/6 Title: File: fileSDMMC.sch Sheet: /sheetSDMMC/ SD_DAT0
SD_DAT1

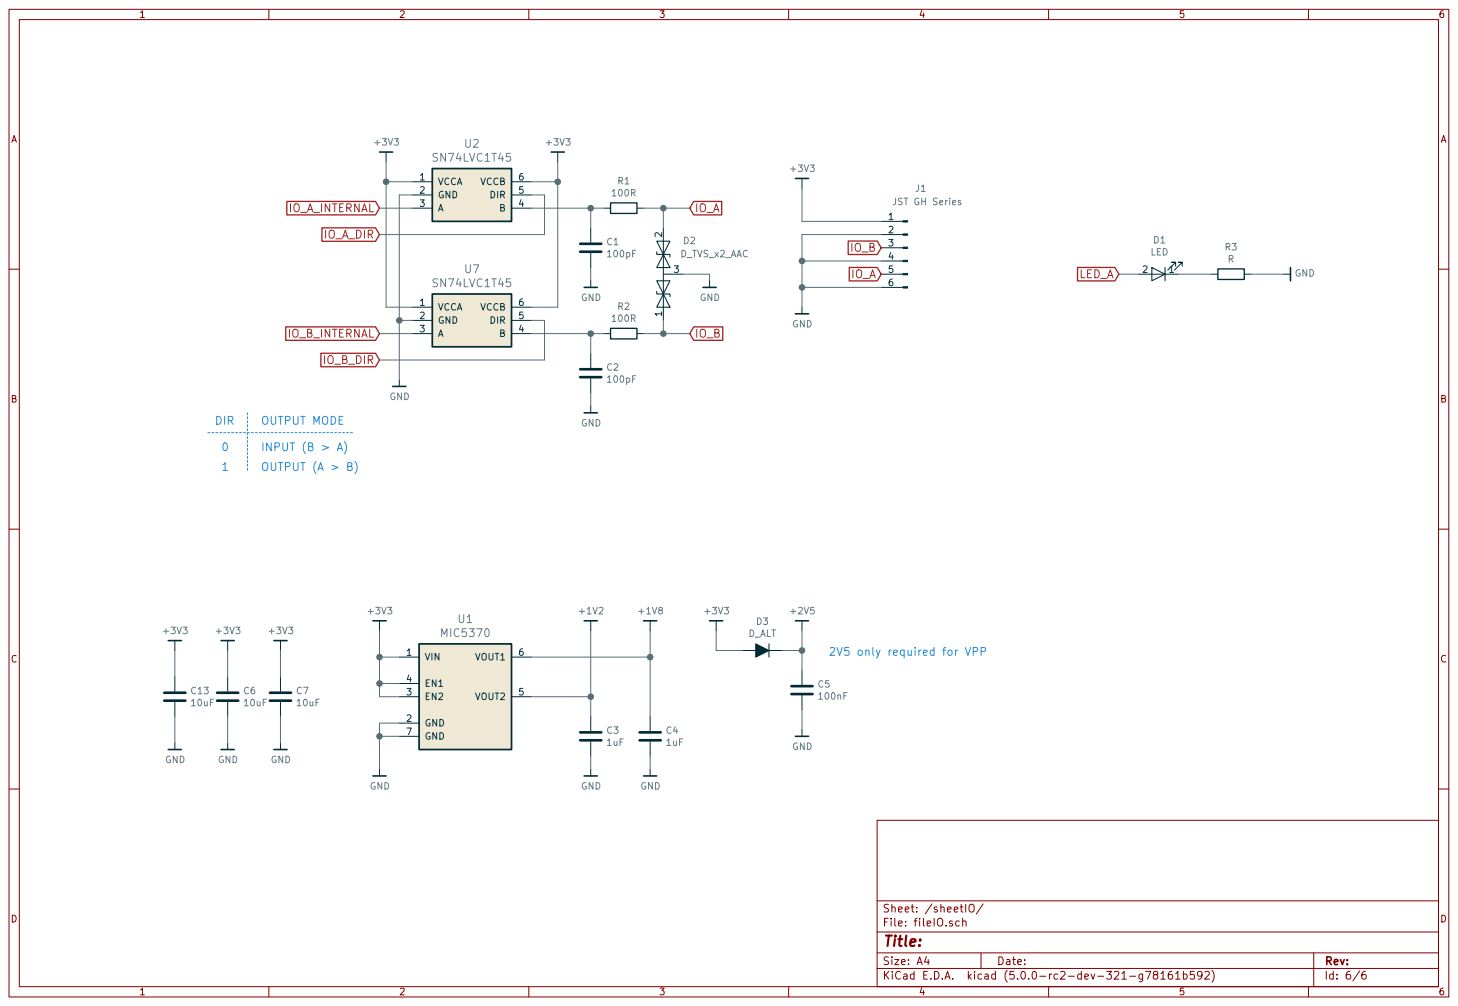
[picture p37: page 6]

2V5 only required for VPP

Id: 6/6 Title: File: fileIO.sch Sheet: /sheetIO/

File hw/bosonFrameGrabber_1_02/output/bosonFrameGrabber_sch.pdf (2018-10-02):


Id: 1/6 Title: File: bosonFrameGrabber.sch Sheet: /

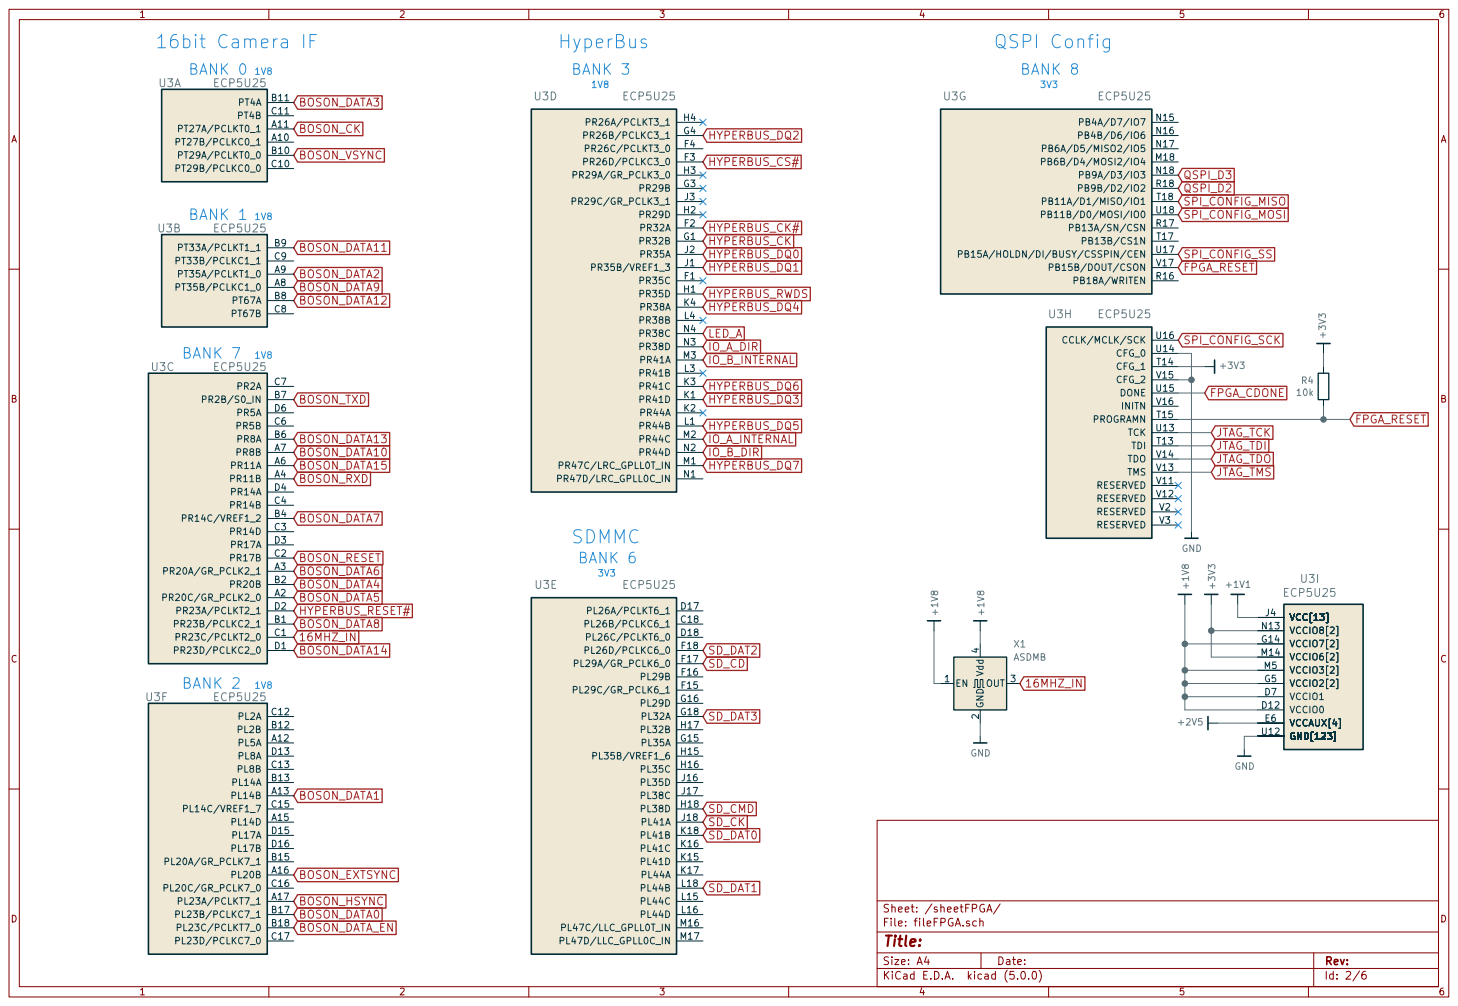
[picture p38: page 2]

Id: 2/6 Title: File: fileFPGA.sch Sheet: /sheetFPGA/

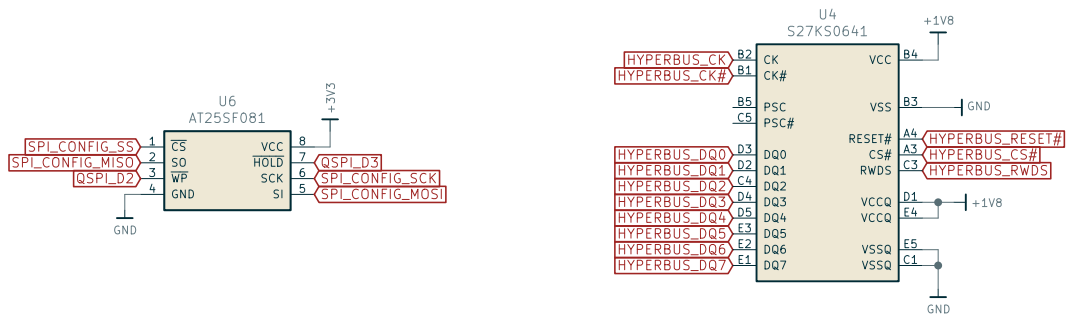
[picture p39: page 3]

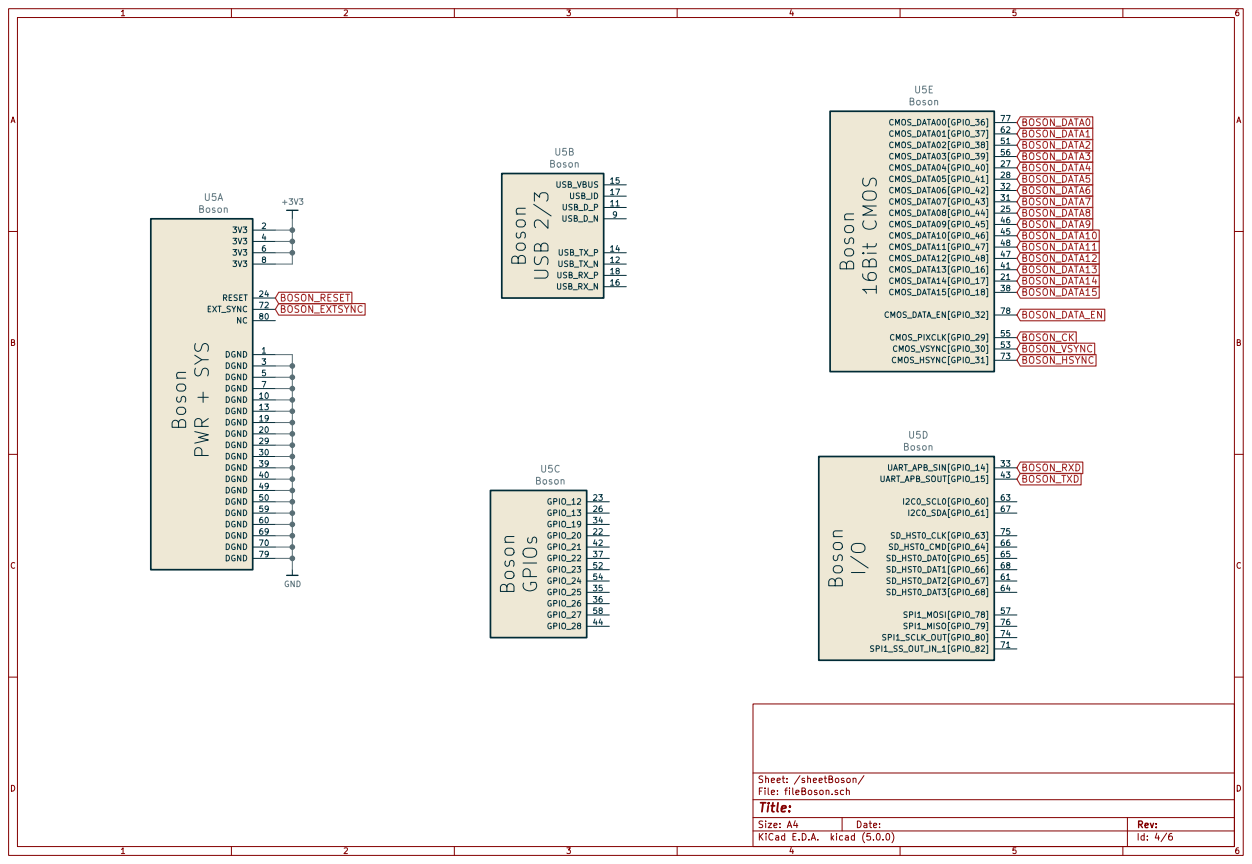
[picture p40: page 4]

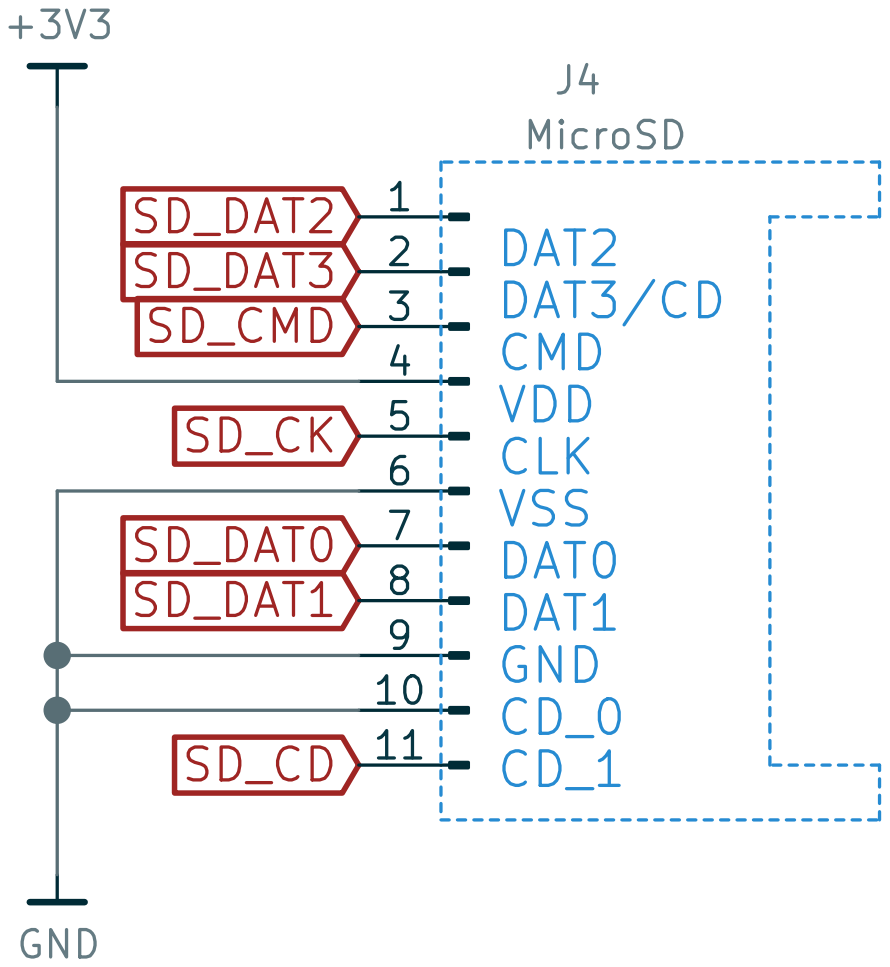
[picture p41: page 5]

Id: 5/6 Title: File: fileSDMMC.sch Sheet: /sheetSDMMC/ SD_DAT0
SD_DAT1

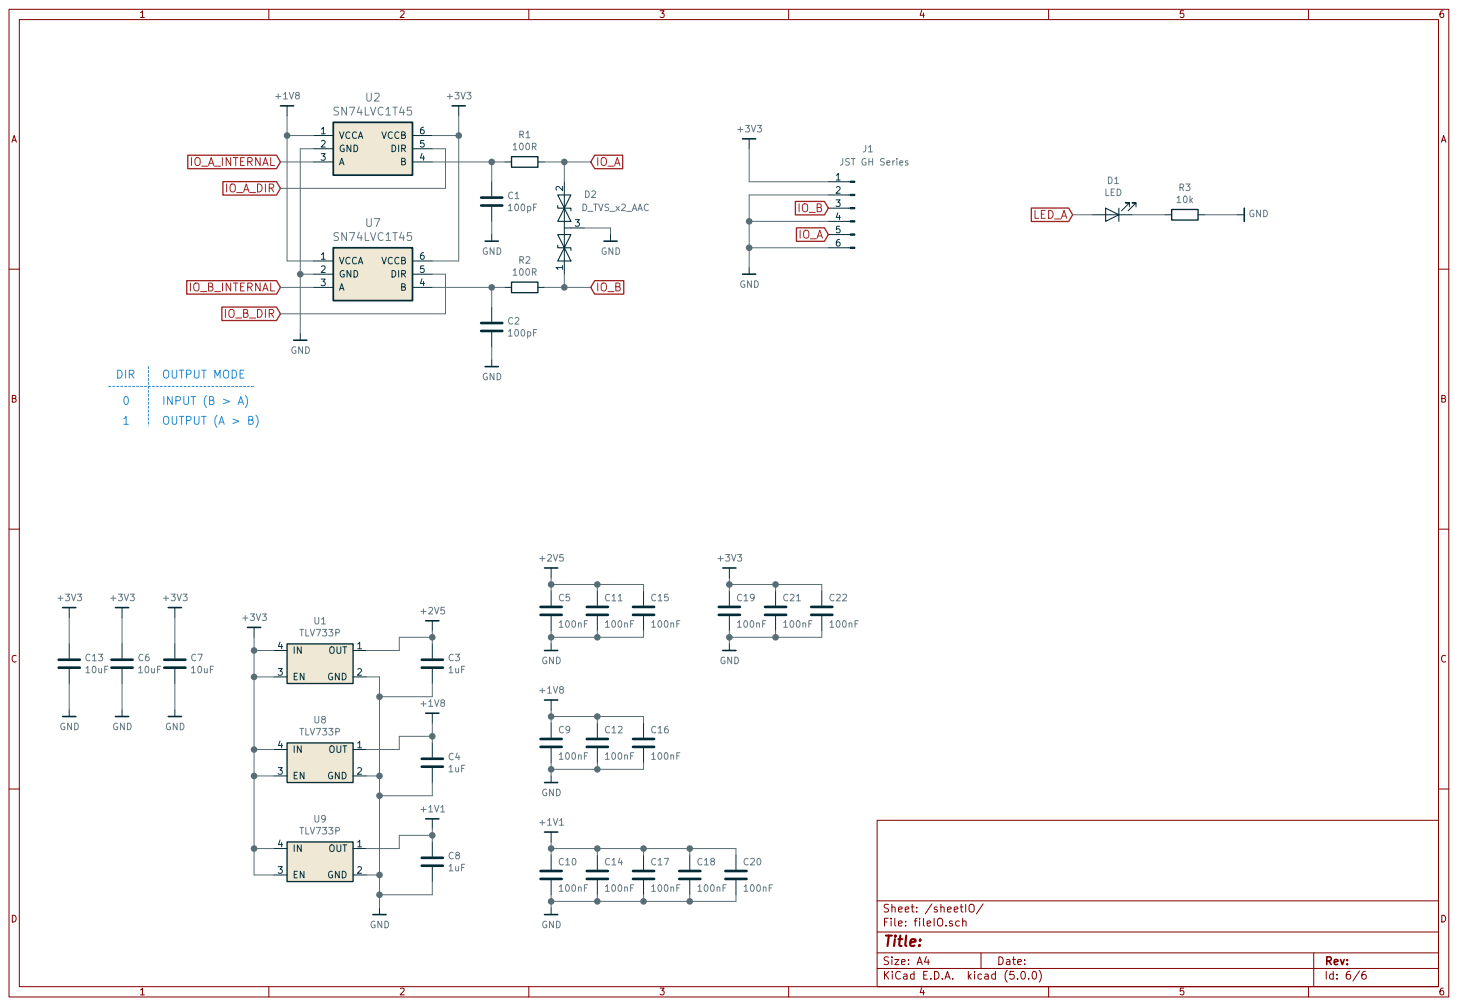
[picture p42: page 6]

Id: 6/6 Title: File: fileIO.sch Sheet: /sheetIO/

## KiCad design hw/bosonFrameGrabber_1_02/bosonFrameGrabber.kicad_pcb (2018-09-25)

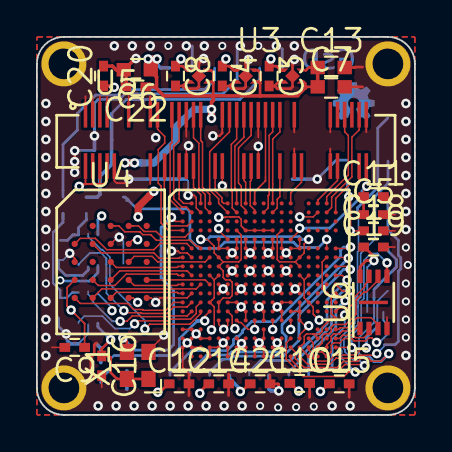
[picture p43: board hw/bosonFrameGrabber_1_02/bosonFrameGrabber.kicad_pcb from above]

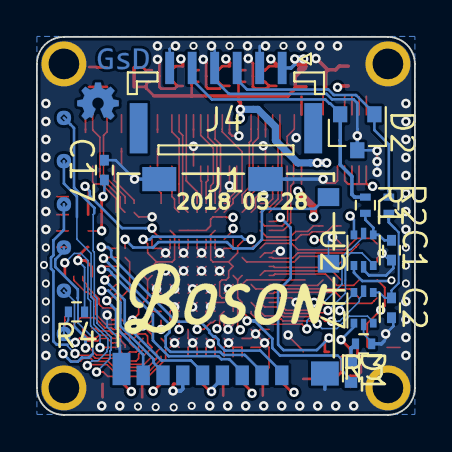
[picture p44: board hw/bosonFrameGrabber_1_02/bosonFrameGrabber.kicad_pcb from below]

Board: 4 copper layers, 21.0 x 21.0 mm, 40 parts (13 on the bottom side), 67 nets.

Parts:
C1, C2: 100pF; C_0402
C3, C4, C8: 1uF; C_0402
C5, C9, C10, C11, C12, C14, C15, C16, C17, C18, C19, C20, C21, C22: 100nF; C_0402
C6, C7, C13: 10uF; C_0603
D1: LED; LED_0402
D2: D_TVS_x2_AAC; SOT-23
J1: JST GH Series; JST_GH_BM06B-GHS-TBT_06x1.25mm_Straight
J4: MicroSD; 1040310811
R1, R2: 100R; R_0402
R3, R4: 10k; R_0402
U1: TLV70725; X2SON
U2, U7: SN74LVC1T45; SOT-666
U3: ECP5U25; csBGA_132
U4: S27KS0641; BGA_24
U5: Boson; DF40_80Pin
U6: AT25SF081; DFN-8-1EP_3x2mm_Pitch0.5mm
U8: TLV71718; X2SON
U9: TLV73311; X2SON
X1: ASDMB; Oscillator_SMD_SeikoEpson_SG210-4pin_2.5x2.0mm

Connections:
16MHZ_IN: U3.C1, X1.3
+1V1: C8.1, C10.1, C14.1, C17.1, C18.1, C20.1, U3.D8, U3.D9, U3.D10, U3.D11, U3.J4, U3.J5, U3.J14, U3.J15, U3.M4, U3.M15, U3.P7, U3.P9, U3.P11, U9.1
+1V8: C4.1, C9.1, C12.1, C16.1, U2.1, U3.D7, U3.D12, U3.G5, U3.G14, U3.H5, U3.H14, U3.M5, U3.N5, U4.B4, U4.D1, U4.E4, U7.1, U8.1, X1.1, X1.4
+2V5: C3.1, C5.1, C11.1, C15.1, U1.1, U3.E6, U3.E13, U3.N6, U3.P13
+3V3: C6.1, C7.1, C13.1, C19.1, C21.1, C22.1, J1.1, J4.4, R4.1, U1.3, U1.4, U2.6, U3.M14, U3.N13, U3.N14, U3.P14, U3.T14, U5.2, U5.4, U5.6, U5.8, U6.8, U7.6, U8.3, U8.4, U9.3, U9.4
BOSON_CK: U3.A11, U5.55
BOSON_DATA0: U3.B17, U5.77
BOSON_DATA1: U3.A13, U5.62
BOSON_DATA2: U3.A9, U5.51
BOSON_DATA3: U3.B11, U5.56
BOSON_DATA4: U3.B2, U5.27
BOSON_DATA5: U3.A2, U5.28
BOSON_DATA6: U3.A3, U5.32
BOSON_DATA7: U3.B4, U5.31
BOSON_DATA8: U3.B1, U5.25
BOSON_DATA9: U3.A8, U5.46
BOSON_DATA10: U3.A7, U5.45
BOSON_DATA11: U3.B9, U5.48
BOSON_DATA12: U3.B8, U5.47
BOSON_DATA13: U3.B6, U5.41
BOSON_DATA14: U3.D1, U5.21
BOSON_DATA15: U3.A6, U5.38
BOSON_DATA_EN: U3.B18, U5.78
BOSON_EXTSYNC: U3.A16, U5.72
BOSON_HSYNC: U3.A17, U5.73
BOSON_RESET: U3.C2, U5.24
BOSON_RXD: U3.A4, U5.33
BOSON_TXD: U3.B7, U5.43
BOSON_VSYNC: U3.B10, U5.53
FPGA_RESET: R4.2, U3.T15, U3.V17
GND: C1.2, C2.2, C3.2, C4.2, C5.2, C6.2, C7.2, C8.2, C9.2, C10.2, C11.2, C12.2, C13.2, C14.2, C15.2, C16.2, C17.2, C18.2, C19.2, C20.2, C21.2, C22.2, D2.3, J1.2, J1.4, J1.6, J4.6, J4.9, J4.10, R3.1, U1.2, U2.2, U3.B3, U3.B16, U3.E5, U3.E7, U3.E8, U3.E9, U3.E10, U3.E11, U3.E12, U3.E14, U3.F5, U3.F6, U3.F7, U3.F8, U3.F9, U3.F10, U3.F11, U3.F12, U3.F13, U3.F14, U3.G2, U3.G6, U3.G7, U3.G8, U3.G9, U3.G10, U3.G11, U3.G12, U3.G13, U3.G17, U3.H6, U3.H7, U3.H8, U3.H9, U3.H10, U3.H11, U3.H12, U3.H13, U3.J6, U3.J7, U3.J8, U3.J9, U3.J10, U3.J11, U3.J12, U3.J13, U3.K5, U3.K6, U3.K7, U3.K8, U3.K9, U3.K10, U3.K11, U3.K12, U3.K13, U3.K14, U3.L2, U3.L5, U3.L6, U3.L7, U3.L8, U3.L9, U3.L10, U3.L11, U3.L12, U3.L13, U3.L14, U3.L17, U3.M6, U3.M7, U3.M8, U3.M9, U3.M10, U3.M11, U3.M12, U3.M13, U3.N7, U3.N8, U3.N9, U3.N10, U3.N11, U3.N12, U3.P5, U3.P6, U3.P8, U3.P10, U3.P12, U3.R1, U3.R2, U3.R3, U3.R10, U3.T1, U3.T2, U3.T3, U3.T4, U3.T5, U3.T6, U3.T7, U3.T8, U3.T9, U3.T10, U3.T11, U3.T12, U3.T16, U3.U1, U3.U2, U3.U3, U3.U4, U3.U5, U3.U6, U3.U7, U3.U8, U3.U9, U3.U10, U3.U11, U3.U12, U3.U14, U3.V4, U3.V5, U3.V6, U3.V7, U3.V8, U3.V9, U3.V10, U3.V15, U4.B3, U4.C1, U4.E5, U5.1, U5.3, U5.5, U5.7, U5.10, U5.13, U5.19, U5.20, U5.29, U5.30, U5.39, U5.40, U5.49, U5.50, U5.59, U5.60, U5.69, U5.70, U5.79, U6.4, U7.2, U8.2, U9.2, X1.2
HYPERBUS_CK: U3.G1, U4.B2
HYPERBUS_CK#: U3.F2, U4.B1
HYPERBUS_CS#: U3.F3, U4.A3
HYPERBUS_DQ0: U3.J2, U4.D3
HYPERBUS_DQ1: U3.J1, U4.D2
HYPERBUS_DQ2: U3.G4, U4.C4
HYPERBUS_DQ3: U3.K1, U4.D4
HYPERBUS_DQ4: U3.K4, U4.D5
HYPERBUS_DQ5: U3.L1, U4.E3
HYPERBUS_DQ6: U3.K3, U4.E2
HYPERBUS_DQ7: U3.M1, U4.E1
HYPERBUS_RESET#: U3.D2, U4.A4
HYPERBUS_RWDS: U3.H1, U4.C3
IO_A: D2.2, J1.5, R1.1
IO_A_DIR: U2.5, U3.N3
IO_A_INTERNAL: U2.3, U3.M2
IO_B: D2.1, J1.3, R2.1
IO_B_DIR: U3.N2, U7.5
IO_B_INTERNAL: U3.M3, U7.3
LED_A: D1.2, U3.N4
unnamed: C1.1, R1.2, U2.4
unnamed: C2.1, R2.2, U7.4
unnamed: D1.1, R3.2
QSPI_D2: U3.R18, U6.3
QSPI_D3: U3.N18, U6.7
SD_CD: J4.11, U3.F17
SD_CK: J4.5, U3.J18
SD_CMD: J4.3, U3.H18
SD_DAT0: J4.7, U3.K18
SD_DAT1: J4.8, U3.L18
SD_DAT2: J4.1, U3.F18
SD_DAT3: J4.2, U3.G18
SPI_CONFIG_MISO: U3.T18, U6.2
SPI_CONFIG_MOSI: U3.U18, U6.5
SPI_CONFIG_SCK: U3.U16, U6.6
SPI_CONFIG_SS: U3.U17, U6.1

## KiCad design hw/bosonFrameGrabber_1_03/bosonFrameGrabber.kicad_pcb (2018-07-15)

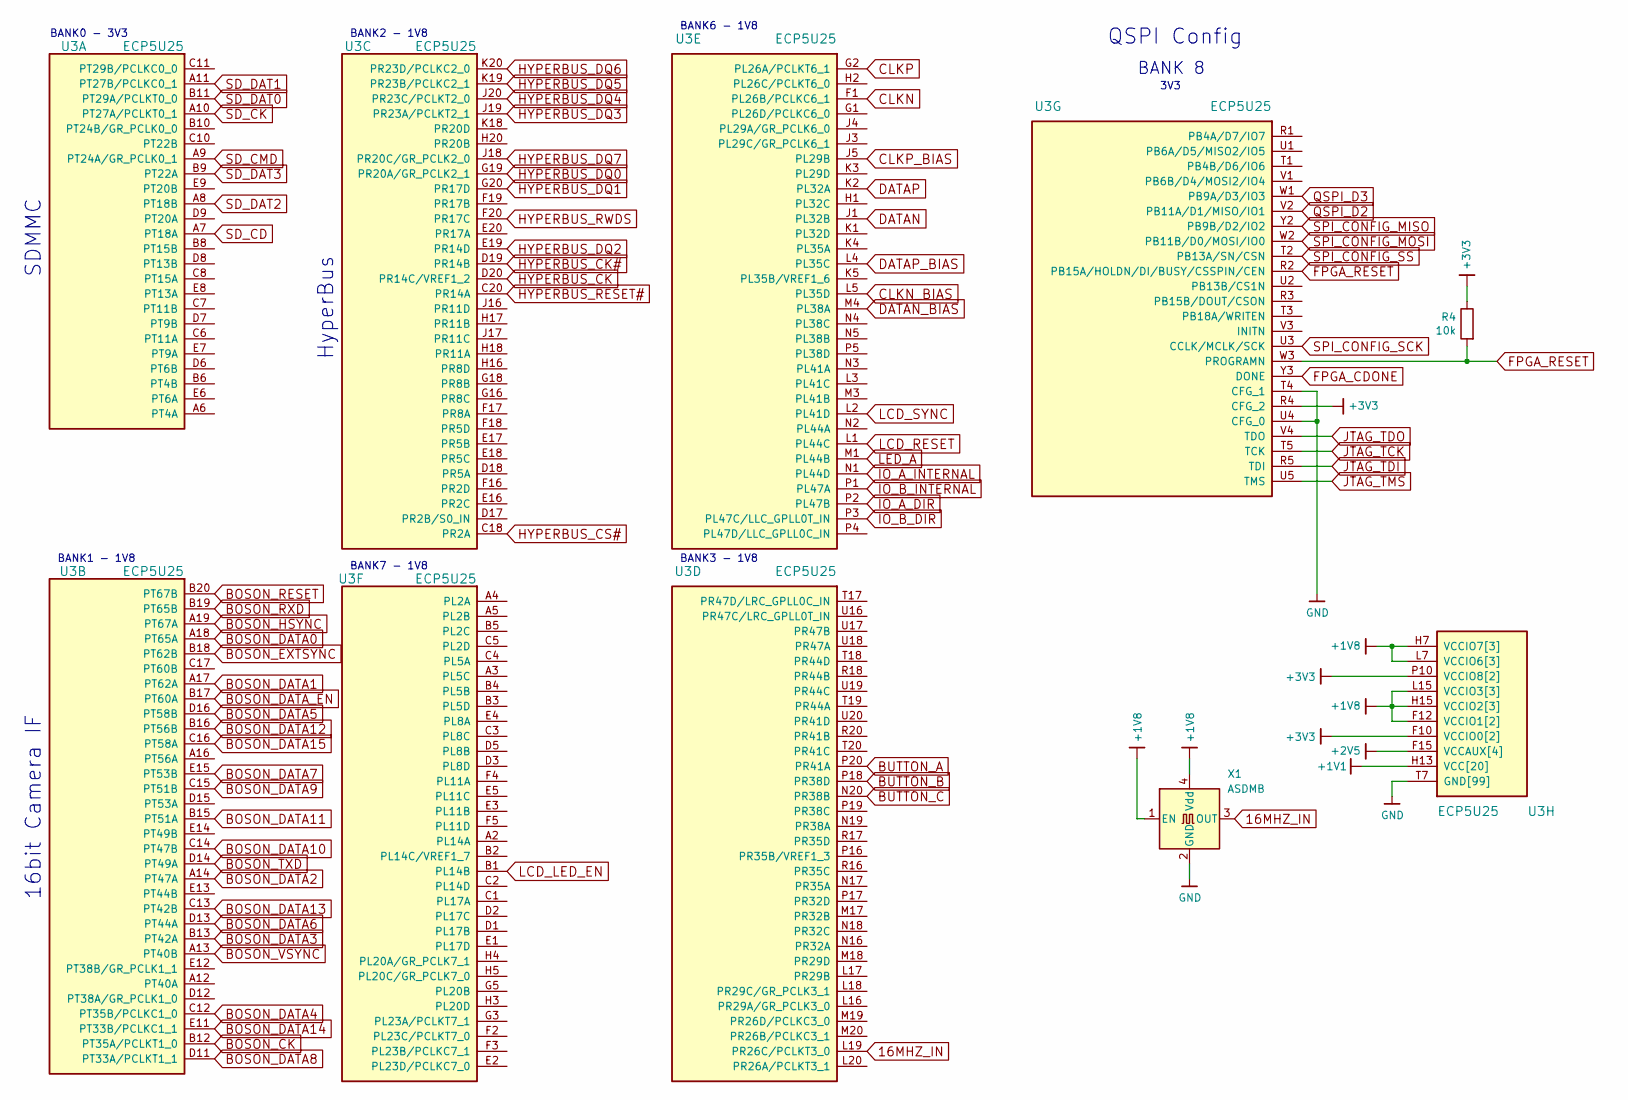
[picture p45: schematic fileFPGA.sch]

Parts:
R4: 10k; R_0402
U3: ECP5U25
X1: ASDMB; Oscillator_SMD_SeikoEpson_SG210-4pin_2.5x2.0mm

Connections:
16MHZ_IN: U3.L19 (PR26C/PCLKT3_0), X1.3 (OUT)
+1V1: U3.H8 (VCC[20]), U3.H9 (VCC[20]), U3.H10 (VCC[20]), U3.H11 (VCC[20]), U3.H12 (VCC[20]), U3.H13 (VCC[20]), U3.J8 (VCC[20]), U3.J13 (VCC[20]), U3.K8 (VCC[20]), U3.K13 (VCC[20]), U3.L8 (VCC[20]), U3.L13 (VCC[20]), U3.M8 (VCC[20]), U3.M13 (VCC[20]), U3.N8 (VCC[20]), U3.N9 (VCC[20]), U3.N10 (VCC[20]), U3.N11 (VCC[20]), U3.N12 (VCC[20]), U3.N13 (VCC[20]); also elsewhere on the board
+1V8: U3.F11 (VCCIO1[2]), U3.F12 (VCCIO1[2]), U3.H6 (VCCIO7[3]), U3.H7 (VCCIO7[3]), U3.H14 (VCCIO2[3]), U3.H15 (VCCIO2[3]), U3.J6 (VCCIO7[3]), U3.J15 (VCCIO2[3]), U3.L6 (VCCIO6[3]), U3.L7 (VCCIO6[3]), U3.L14 (VCCIO3[3]), U3.L15 (VCCIO3[3]), U3.M6 (VCCIO6[3]), U3.M15 (VCCIO3[3]), X1.1 (EN), X1.4 (Vdd); also elsewhere on the board
+2V5: U3.F6 (VCCAUX[4]), U3.F15 (VCCAUX[4]), U3.P6 (VCCAUX[4]), U3.P15 (VCCAUX[4]); also elsewhere on the board
+3V3: R4.1, U3.F9 (VCCIO0[2]), U3.F10 (VCCIO0[2]), U3.P9 (VCCIO8[2]), U3.P10 (VCCIO8[2]), U3.R4 (CFG_2); also elsewhere on the board
BOSON_CK: U3.B12 (PT35A/PCLKT1_0); also elsewhere on the board
BOSON_DATA0: U3.A18 (PT65A); also elsewhere on the board
BOSON_DATA1: U3.A17 (PT62A); also elsewhere on the board
BOSON_DATA2: U3.A14 (PT47A); also elsewhere on the board
BOSON_DATA3: U3.B13 (PT42A); also elsewhere on the board
BOSON_DATA4: U3.C12 (PT35B/PCLKC1_0); also elsewhere on the board
BOSON_DATA5: U3.D16 (PT58B); also elsewhere on the board
BOSON_DATA6: U3.D13 (PT44A); also elsewhere on the board
BOSON_DATA7: U3.E15 (PT53B); also elsewhere on the board
BOSON_DATA8: U3.D11 (PT33A/PCLKT1_1); also elsewhere on the board
BOSON_DATA9: U3.C15 (PT51B); also elsewhere on the board
BOSON_DATA10: U3.C14 (PT47B); also elsewhere on the board
BOSON_DATA11: U3.B15 (PT51A); also elsewhere on the board
BOSON_DATA12: U3.B16 (PT56B); also elsewhere on the board
BOSON_DATA13: U3.C13 (PT42B); also elsewhere on the board
BOSON_DATA14: U3.E11 (PT33B/PCLKC1_1); also elsewhere on the board
BOSON_DATA15: U3.C16 (PT58A); also elsewhere on the board
BOSON_DATA_EN: U3.B17 (PT60A); also elsewhere on the board
BOSON_EXTSYNC: U3.B18 (PT62B); also elsewhere on the board
BOSON_HSYNC: U3.A19 (PT67A); also elsewhere on the board
BOSON_RESET: U3.B20 (PT67B); also elsewhere on the board
BOSON_RXD: U3.B19 (PT65B); also elsewhere on the board
BOSON_TXD: U3.D14 (PT49A); also elsewhere on the board
BOSON_VSYNC: U3.A13 (PT40B); also elsewhere on the board
BUTTON_A: U3.P20 (PR41A); also elsewhere on the board
BUTTON_B: U3.P18 (PR38D); also elsewhere on the board
BUTTON_C: U3.N20 (PR38B); also elsewhere on the board
CLKN: U3.F1 (PL26B/PCLKC6_1); also elsewhere on the board
CLKN_BIAS: U3.L5 (PL35D); also elsewhere on the board
CLKP: U3.G2 (PL26A/PCLKT6_1); also elsewhere on the board
CLKP_BIAS: U3.J5 (PL29B); also elsewhere on the board
DATAN: U3.J1 (PL32B); also elsewhere on the board
DATAN_BIAS: U3.M4 (PL38A); also elsewhere on the board
DATAP: U3.K2 (PL32A); also elsewhere on the board
DATAP_BIAS: U3.L4 (PL35C); also elsewhere on the board
FPGA_CDONE: U3.Y3 (DONE)
FPGA_RESET: R4.2, U3.R2 (PB15A/HOLDN/DI/BUSY/CSSPIN/CEN), U3.W3 (PROGRAMN)
GND: U3.B7 (GND[99]), U3.B14 (GND[99]), U3.C19 (GND[99]), U3.D4 (GND[99]), U3.F7 (GND[99]), U3.F8 (GND[99]), U3.F13 (GND[99]), U3.F14 (GND[99]), U3.G4 (GND[99]), U3.G6 (GND[99]), U3.G7 (GND[99]), U3.G8 (GND[99]), U3.G9 (GND[99]), U3.G10 (GND[99]), U3.G11 (GND[99]), U3.G12 (GND[99]), U3.G13 (GND[99]), U3.G14 (GND[99]), U3.G15 (GND[99]), U3.G17 (GND[99]), U3.H19 (GND[99]), U3.J2 (GND[99]), U3.J7 (GND[99]), U3.J9 (GND[99]), U3.J10 (GND[99]), U3.J11 (GND[99]), U3.J12 (GND[99]), U3.J14 (GND[99]), U3.K6 (GND[99]), U3.K7 (GND[99]), U3.K9 (GND[99]), U3.K10 (GND[99]), U3.K11 (GND[99]), U3.K12 (GND[99]), U3.K14 (GND[99]), U3.K15 (GND[99]), U3.L9 (GND[99]), U3.L10 (GND[99]), U3.L11 (GND[99]), U3.L12 (GND[99]), U3.M2 (GND[99]), U3.M7 (GND[99]), U3.M9 (GND[99]), U3.M10 (GND[99]), U3.M11 (GND[99]), U3.M12 (GND[99]), U3.M14 (GND[99]), U3.M16 (GND[99]), U3.N6 (GND[99]), U3.N7 (GND[99]), U3.N14 (GND[99]), U3.N15 (GND[99]), U3.P7 (GND[99]), U3.P8 (GND[99]), U3.P11 (GND[99]), U3.P12 (GND[99]), U3.P13 (GND[99]), U3.P14 (GND[99]), U3.R19 (GND[99]), U3.T4 (CFG_1), U3.T6 (GND[99]), U3.T7 (GND[99]), U3.T8 (GND[99]), U3.T9 (GND[99]), U3.T10 (GND[99]), U3.U4 (CFG_0), U3.U6 (GND[99]), U3.U7 (GND[99]), U3.U8 (GND[99]), U3.U9 (GND[99]), U3.U10 (GND[99]), U3.U11 (GND[99]), U3.U12 (GND[99]), U3.U13 (GND[99]), U3.U14 (GND[99]), U3.V5 (GND[99]), U3.V6 (GND[99]), U3.V7 (GND[99]), U3.V8 (GND[99]), U3.V9 (GND[99]), U3.V10 (GND[99]), U3.V11 (GND[99]), U3.V12 (GND[99]), U3.V13 (GND[99]), U3.V14 (GND[99]), U3.V15 (GND[99]), U3.V16 (GND[99]), U3.V19 (GND[99]), U3.V20 (GND[99]), U3.W6 (GND[99]), U3.W7 (GND[99]), U3.W12 (GND[99]), U3.W15 (GND[99]), U3.W16 (GND[99]), U3.W19 (GND[99]), U3.Y5 (GND[99]), U3.Y6 (GND[99]), U3.Y7 (GND[99]), U3.Y8 (GND[99]), U3.Y11 (GND[99]), U3.Y12 (GND[99]), X1.2 (GND); also elsewhere on the board
HYPERBUS_CK: U3.D20 (PR14C/VREF1_2); also elsewhere on the board
HYPERBUS_CK#: U3.D19 (PR14B); also elsewhere on the board
HYPERBUS_CS#: U3.C18 (PR2A); also elsewhere on the board
HYPERBUS_DQ0: U3.G19 (PR20A/GR_PCLK2_1); also elsewhere on the board
HYPERBUS_DQ1: U3.G20 (PR17D); also elsewhere on the board
HYPERBUS_DQ2: U3.E19 (PR14D); also elsewhere on the board
HYPERBUS_DQ3: U3.J19 (PR23A/PCLKT2_1); also elsewhere on the board
HYPERBUS_DQ4: U3.J20 (PR23C/PCLKT2_0); also elsewhere on the board
HYPERBUS_DQ5: U3.K19 (PR23B/PCLKC2_1); also elsewhere on the board
HYPERBUS_DQ6: U3.K20 (PR23D/PCLKC2_0); also elsewhere on the board
HYPERBUS_DQ7: U3.J18 (PR20C/GR_PCLK2_0); also elsewhere on the board
HYPERBUS_RESET#: U3.C20 (PR14A); also elsewhere on the board
HYPERBUS_RWDS: U3.F20 (PR17C); also elsewhere on the board
IO_A_DIR: U3.P2 (PL47B); also elsewhere on the board
IO_A_INTERNAL: U3.N1 (PL44D); also elsewhere on the board
IO_B_DIR: U3.P3 (PL47C/LLC_GPLL0T_IN); also elsewhere on the board
IO_B_INTERNAL: U3.P1 (PL47A); also elsewhere on the board
JTAG_TCK: U3.T5 (TCK); also elsewhere on the board
JTAG_TDI: U3.R5 (TDI); also elsewhere on the board
JTAG_TDO: U3.V4 (TDO); also elsewhere on the board
JTAG_TMS: U3.U5 (TMS); also elsewhere on the board
LCD_LED_EN: U3.B1 (PL14B); also elsewhere on the board
LCD_RESET: U3.L1 (PL44C); also elsewhere on the board
LCD_SYNC: U3.L2 (PL41D); also elsewhere on the board
LED_A: U3.M1 (PL44B); also elsewhere on the board
QSPI_D2: U3.V2 (PB11A/D1/MISO/IO1); also elsewhere on the board
QSPI_D3: U3.W1 (PB9A/D3/IO3); also elsewhere on the board
SD_CD: U3.A7 (PT18A); also elsewhere on the board
SD_CK: U3.A10 (PT27A/PCLKT0_1); also elsewhere on the board
SD_CMD: U3.A9 (PT24A/GR_PCLK0_1); also elsewhere on the board
SD_DAT0: U3.B11 (PT29A/PCLKT0_0); also elsewhere on the board
SD_DAT1: U3.A11 (PT27B/PCLKC0_1); also elsewhere on the board
SD_DAT2: U3.A8 (PT18B); also elsewhere on the board
SD_DAT3: U3.B9 (PT22A); also elsewhere on the board
SPI_CONFIG_MISO: U3.Y2 (PB9B/D2/IO2); also elsewhere on the board
SPI_CONFIG_MOSI: U3.W2 (PB11B/D0/MOSI/IO0); also elsewhere on the board
SPI_CONFIG_SCK: U3.U3 (CCLK/MCLK/SCK); also elsewhere on the board
SPI_CONFIG_SS: U3.T2 (PB13A/SN/CSN); also elsewhere on the board

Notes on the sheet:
BANK 8
3V3
QSPI Config
HyperBus
SDMMC
16bit Camera IF
BANK0 - 3V3
BANK1 - 1V8
BANK7 - 1V8
BANK2 - 1V8
BANK6 - 1V8
BANK3 - 1V8

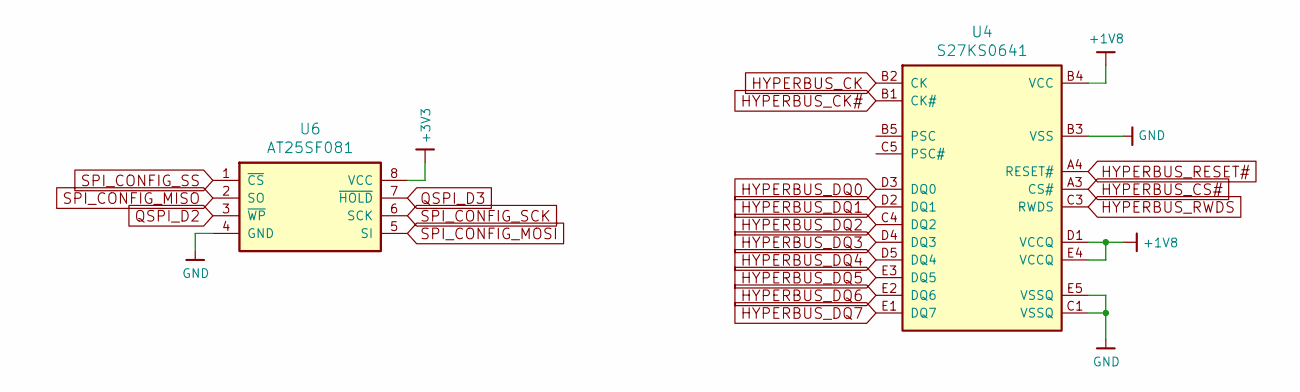
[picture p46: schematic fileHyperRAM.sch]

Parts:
U4: S27KS0641; BGA_24
U6: AT25SF081; DFN-8-1EP_3x2mm_Pitch0.5mm

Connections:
+1V8: U4.B4 (VCC), U4.D1 (VCCQ), U4.E4 (VCCQ); also elsewhere on the board
+3V3: U6.8 (VCC); also elsewhere on the board
GND: U4.B3 (VSS), U4.C1 (VSSQ), U4.E5 (VSSQ), U6.4 (GND); also elsewhere on the board
HYPERBUS_CK: U4.B2 (CK); also elsewhere on the board
HYPERBUS_CK#: U4.B1 (CK#); also elsewhere on the board
HYPERBUS_CS#: U4.A3 (CS#); also elsewhere on the board
HYPERBUS_DQ0: U4.D3 (DQ0); also elsewhere on the board
HYPERBUS_DQ1: U4.D2 (DQ1); also elsewhere on the board
HYPERBUS_DQ2: U4.C4 (DQ2); also elsewhere on the board
HYPERBUS_DQ3: U4.D4 (DQ3); also elsewhere on the board
HYPERBUS_DQ4: U4.D5 (DQ4); also elsewhere on the board
HYPERBUS_DQ5: U4.E3 (DQ5); also elsewhere on the board
HYPERBUS_DQ6: U4.E2 (DQ6); also elsewhere on the board
HYPERBUS_DQ7: U4.E1 (DQ7); also elsewhere on the board
HYPERBUS_RESET#: U4.A4 (RESET#); also elsewhere on the board
HYPERBUS_RWDS: U4.C3 (RWDS); also elsewhere on the board
QSPI_D2: U6.3 (~WP); also elsewhere on the board
QSPI_D3: U6.7 (~HOLD); also elsewhere on the board
SPI_CONFIG_MISO: U6.2 (SO); also elsewhere on the board
SPI_CONFIG_MOSI: U6.5 (SI); also elsewhere on the board
SPI_CONFIG_SCK: U6.6 (SCK); also elsewhere on the board
SPI_CONFIG_SS: U6.1 (~CS); also elsewhere on the board

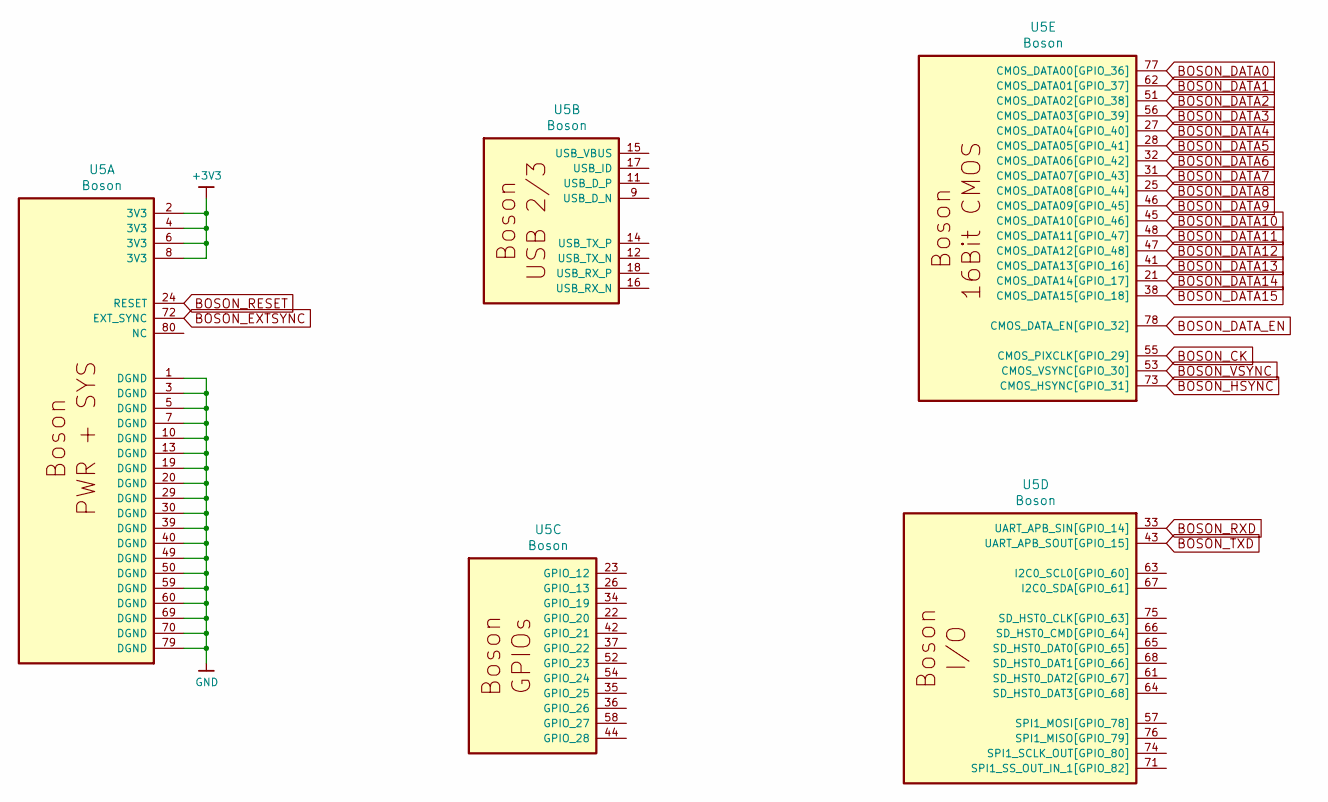
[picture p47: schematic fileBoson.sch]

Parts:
U5: Boson

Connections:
+3V3: U5.2 (3V3), U5.4 (3V3), U5.6 (3V3), U5.8 (3V3); also elsewhere on the board
BOSON_CK: U5.55 (CMOS_PIXCLK[GPIO_29]); also elsewhere on the board
BOSON_DATA0: U5.77 (CMOS_DATA00[GPIO_36]); also elsewhere on the board
BOSON_DATA1: U5.62 (CMOS_DATA01[GPIO_37]); also elsewhere on the board
BOSON_DATA2: U5.51 (CMOS_DATA02[GPIO_38]); also elsewhere on the board
BOSON_DATA3: U5.56 (CMOS_DATA03[GPIO_39]); also elsewhere on the board
BOSON_DATA4: U5.27 (CMOS_DATA04[GPIO_40]); also elsewhere on the board
BOSON_DATA5: U5.28 (CMOS_DATA05[GPIO_41]); also elsewhere on the board
BOSON_DATA6: U5.32 (CMOS_DATA06[GPIO_42]); also elsewhere on the board
BOSON_DATA7: U5.31 (CMOS_DATA07[GPIO_43]); also elsewhere on the board
BOSON_DATA8: U5.25 (CMOS_DATA08[GPIO_44]); also elsewhere on the board
BOSON_DATA9: U5.46 (CMOS_DATA09[GPIO_45]); also elsewhere on the board
BOSON_DATA10: U5.45 (CMOS_DATA10[GPIO_46]); also elsewhere on the board
BOSON_DATA11: U5.48 (CMOS_DATA11[GPIO_47]); also elsewhere on the board
BOSON_DATA12: U5.47 (CMOS_DATA12[GPIO_48]); also elsewhere on the board
BOSON_DATA13: U5.41 (CMOS_DATA13[GPIO_16]); also elsewhere on the board
BOSON_DATA14: U5.21 (CMOS_DATA14[GPIO_17]); also elsewhere on the board
BOSON_DATA15: U5.38 (CMOS_DATA15[GPIO_18]); also elsewhere on the board
BOSON_DATA_EN: U5.78 (CMOS_DATA_EN[GPIO_32]); also elsewhere on the board
BOSON_EXTSYNC: U5.72 (EXT_SYNC); also elsewhere on the board
BOSON_HSYNC: U5.73 (CMOS_HSYNC[GPIO_31]); also elsewhere on the board
BOSON_RESET: U5.24 (RESET); also elsewhere on the board
BOSON_RXD: U5.33 (UART_APB_SIN[GPIO_14]); also elsewhere on the board
BOSON_TXD: U5.43 (UART_APB_SOUT[GPIO_15]); also elsewhere on the board
BOSON_VSYNC: U5.53 (CMOS_VSYNC[GPIO_30]); also elsewhere on the board
GND: U5.1 (DGND), U5.3 (DGND), U5.5 (DGND), U5.7 (DGND), U5.10 (DGND), U5.13 (DGND), U5.19 (DGND), U5.20 (DGND), U5.29 (DGND), U5.30 (DGND), U5.39 (DGND), U5.40 (DGND), U5.49 (DGND), U5.50 (DGND), U5.59 (DGND), U5.60 (DGND), U5.69 (DGND), U5.70 (DGND), U5.79 (DGND); also elsewhere on the board

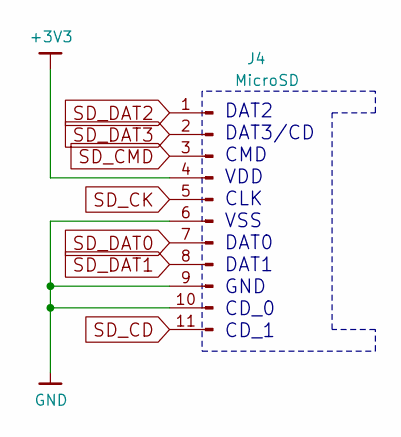
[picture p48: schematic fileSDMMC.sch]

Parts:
J4: MicroSD; 1040310811

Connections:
+3V3: J4.4; also elsewhere on the board
GND: J4.6, J4.9, J4.10; also elsewhere on the board
SD_CD: J4.11; also elsewhere on the board
SD_CK: J4.5; also elsewhere on the board
SD_CMD: J4.3; also elsewhere on the board
SD_DAT0: J4.7; also elsewhere on the board
SD_DAT1: J4.8; also elsewhere on the board
SD_DAT2: J4.1; also elsewhere on the board
SD_DAT3: J4.2; also elsewhere on the board

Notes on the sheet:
DAT2 DAT3/CD CMD VDD CLK VSS DAT0 DAT1 GND CD_0 CD_1

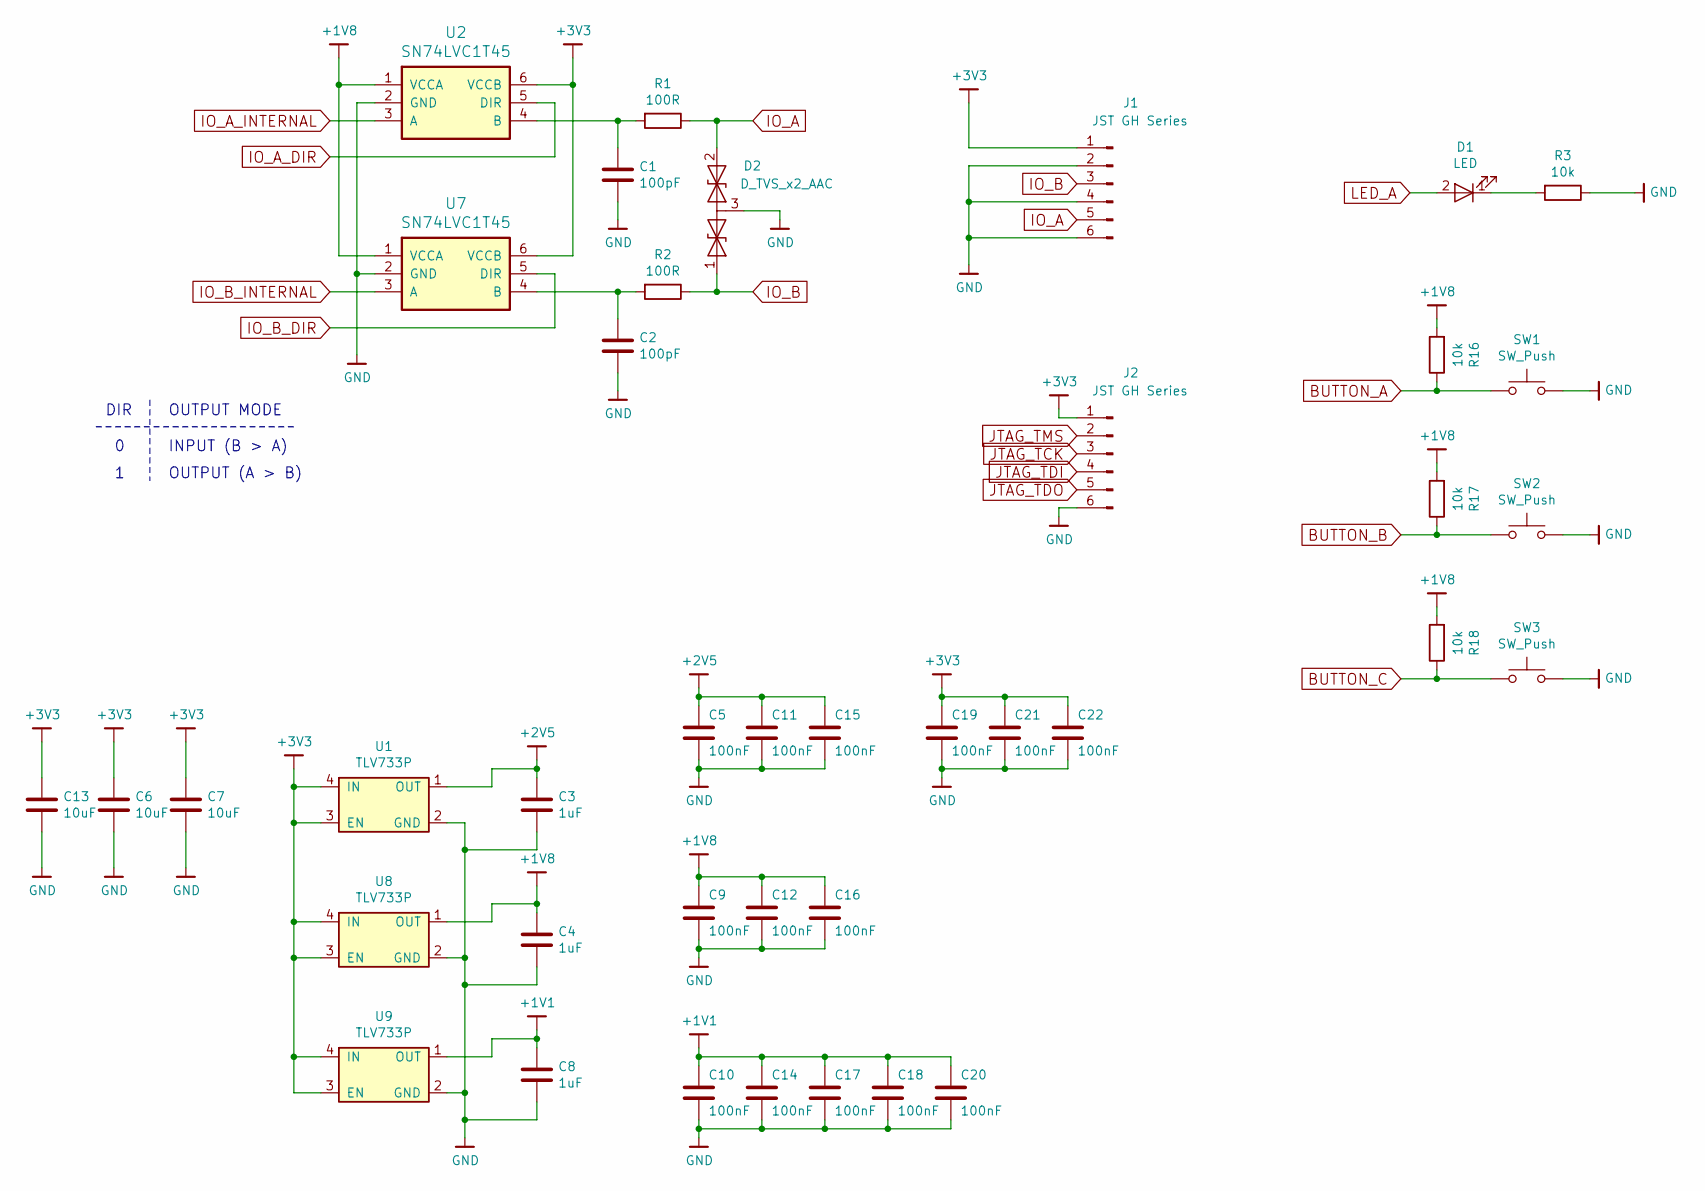
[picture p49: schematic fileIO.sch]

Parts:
C1, C2: 100pF; C_0402
C3, C4, C8: 1uF; C_0402
C5, C9, C10, C11, C12, C14, C15, C16, C17, C18, C19, C20, C21, C22: 100nF; C_0402
C6, C7, C13: 10uF; C_0603
D1: LED; LED_0603
D2: D_TVS_x2_AAC; SOT-23
J1, J2: JST GH Series; JST_GH_BM06B-GHS-TBT_06x1.25mm_Straight
R1, R2: 100R; R_0402
R3, R16, R17, R18: 10k; R_0402
SW1, SW2, SW3: SW_Push; SW_SPST_EVQP0
U1, U8, U9: TLV733P; X2SON
U2, U7: SN74LVC1T45; SOT-666

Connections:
+1V1: C8.1, C10.1, C14.1, C17.1, C18.1, C20.1, U9.1 (OUT); also elsewhere on the board
+1V8: C4.1, C9.1, C12.1, C16.1, R16.2, R17.2, R18.2, U2.1 (VCCA), U7.1 (VCCA), U8.1 (OUT); also elsewhere on the board
+2V5: C3.1, C5.1, C11.1, C15.1, U1.1 (OUT); also elsewhere on the board
+3V3: C6.1, C7.1, C13.1, C19.1, C21.1, C22.1, J1.1, J2.1, U1.3 (EN), U1.4 (IN), U2.6 (VCCB), U7.6 (VCCB), U8.3 (EN), U8.4 (IN), U9.3 (EN), U9.4 (IN); also elsewhere on the board
BUTTON_A: R16.1, SW1.1; also elsewhere on the board
BUTTON_B: R17.1, SW2.1; also elsewhere on the board
BUTTON_C: R18.1, SW3.1; also elsewhere on the board
GND: C1.2, C2.2, C3.2, C4.2, C5.2, C6.2, C7.2, C8.2, C9.2, C10.2, C11.2, C12.2, C13.2, C14.2, C15.2, C16.2, C17.2, C18.2, C19.2, C20.2, C21.2, C22.2, D2.3 (common), J1.2, J1.4, J1.6, J2.6, R3.1, SW1.2, SW2.2, SW3.2, U1.2 (GND), U2.2 (GND), U7.2 (GND), U8.2 (GND), U9.2 (GND); also elsewhere on the board
IO_A: D2.2 (A2), J1.5, R1.1
IO_A_DIR: U2.5 (DIR); also elsewhere on the board
IO_A_INTERNAL: U2.3 (A); also elsewhere on the board
IO_B: D2.1 (A1), J1.3, R2.1
IO_B_DIR: U7.5 (DIR); also elsewhere on the board
IO_B_INTERNAL: U7.3 (A); also elsewhere on the board
JTAG_TCK: J2.3; also elsewhere on the board
JTAG_TDI: J2.4; also elsewhere on the board
JTAG_TDO: J2.5; also elsewhere on the board
JTAG_TMS: J2.2; also elsewhere on the board
LED_A: D1.2 (A); also elsewhere on the board
unnamed: C1.1, R1.2, U2.4 (B)
unnamed: C2.1, R2.2, U7.4 (B)
unnamed: D1.1 (K), R3.2

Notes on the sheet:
DIR
INPUT (B > A)
OUTPUT (A > B)
OUTPUT MODE

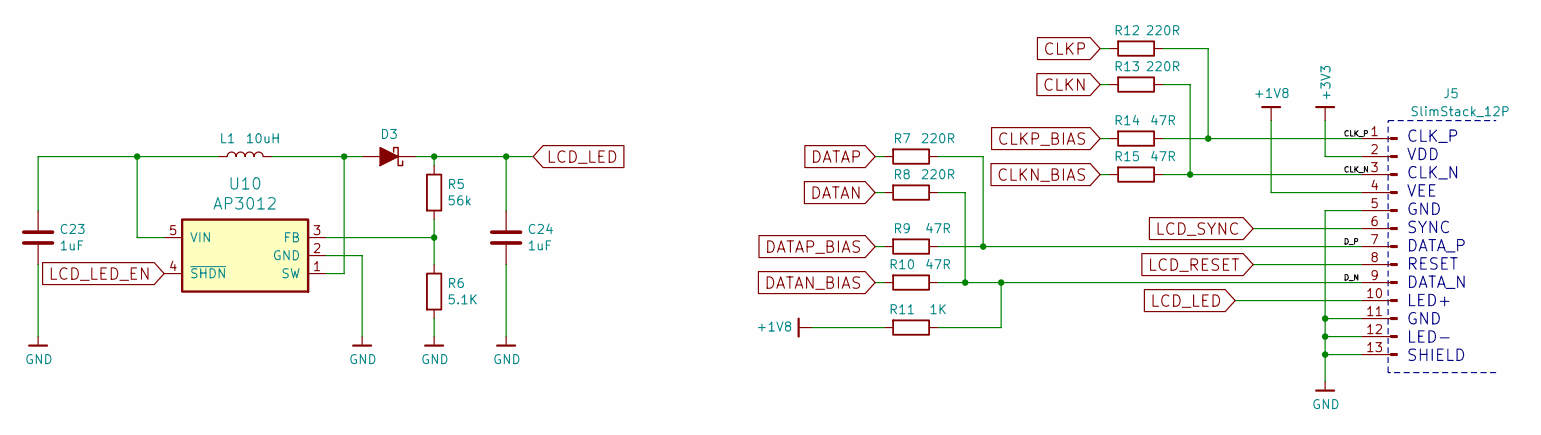
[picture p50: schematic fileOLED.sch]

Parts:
C23, C24: 1uF; C_0603
D3: D_Schottky_ALT; D_SOD-123F
J5: SlimStack_12P
L1: 10uH; L_0603
R5: 56k; R_0603
R6: 5.1K; R_0603
R7, R8, R12, R13: 220R; R_0402
R9, R10, R14, R15: 47R; R_0402
R11: 1K; R_0402
U10: AP3012; SOT-23-5

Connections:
+1V8: J5.4, R11.2; also elsewhere on the board
+3V3: J5.2; also elsewhere on the board
/sheetOLED/CLK_N: J5.3, R13.1, R15.1
/sheetOLED/CLK_P: J5.1, R12.1, R14.1
/sheetOLED/D_N: J5.9, R8.1, R10.1, R11.1
/sheetOLED/D_P: J5.7, R7.1, R9.1
CLKN: R13.2; also elsewhere on the board
CLKN_BIAS: R15.2; also elsewhere on the board
CLKP: R12.2; also elsewhere on the board
CLKP_BIAS: R14.2; also elsewhere on the board
DATAN: R8.2; also elsewhere on the board
DATAN_BIAS: R10.2; also elsewhere on the board
DATAP: R7.2; also elsewhere on the board
DATAP_BIAS: R9.2; also elsewhere on the board
GND: C23.2, C24.2, J5.5, J5.11, J5.12, J5.13, R6.2, U10.2 (GND); also elsewhere on the board
LCD_LED: C24.1, D3.1 (K), J5.10, R5.1
LCD_LED_EN: U10.4 (~SHDN); also elsewhere on the board
LCD_RESET: J5.8; also elsewhere on the board
LCD_SYNC: J5.6; also elsewhere on the board
unnamed: C23.1, L1.1, U10.5 (VIN)
unnamed: D3.2 (A), L1.2, U10.1 (SW)
unnamed: R5.2, R6.1, U10.3 (FB)

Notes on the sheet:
CLK_P VDD CLK_N VEE GND SYNC DATA_P RESET DATA_N LED+ GND LED- SHIELD

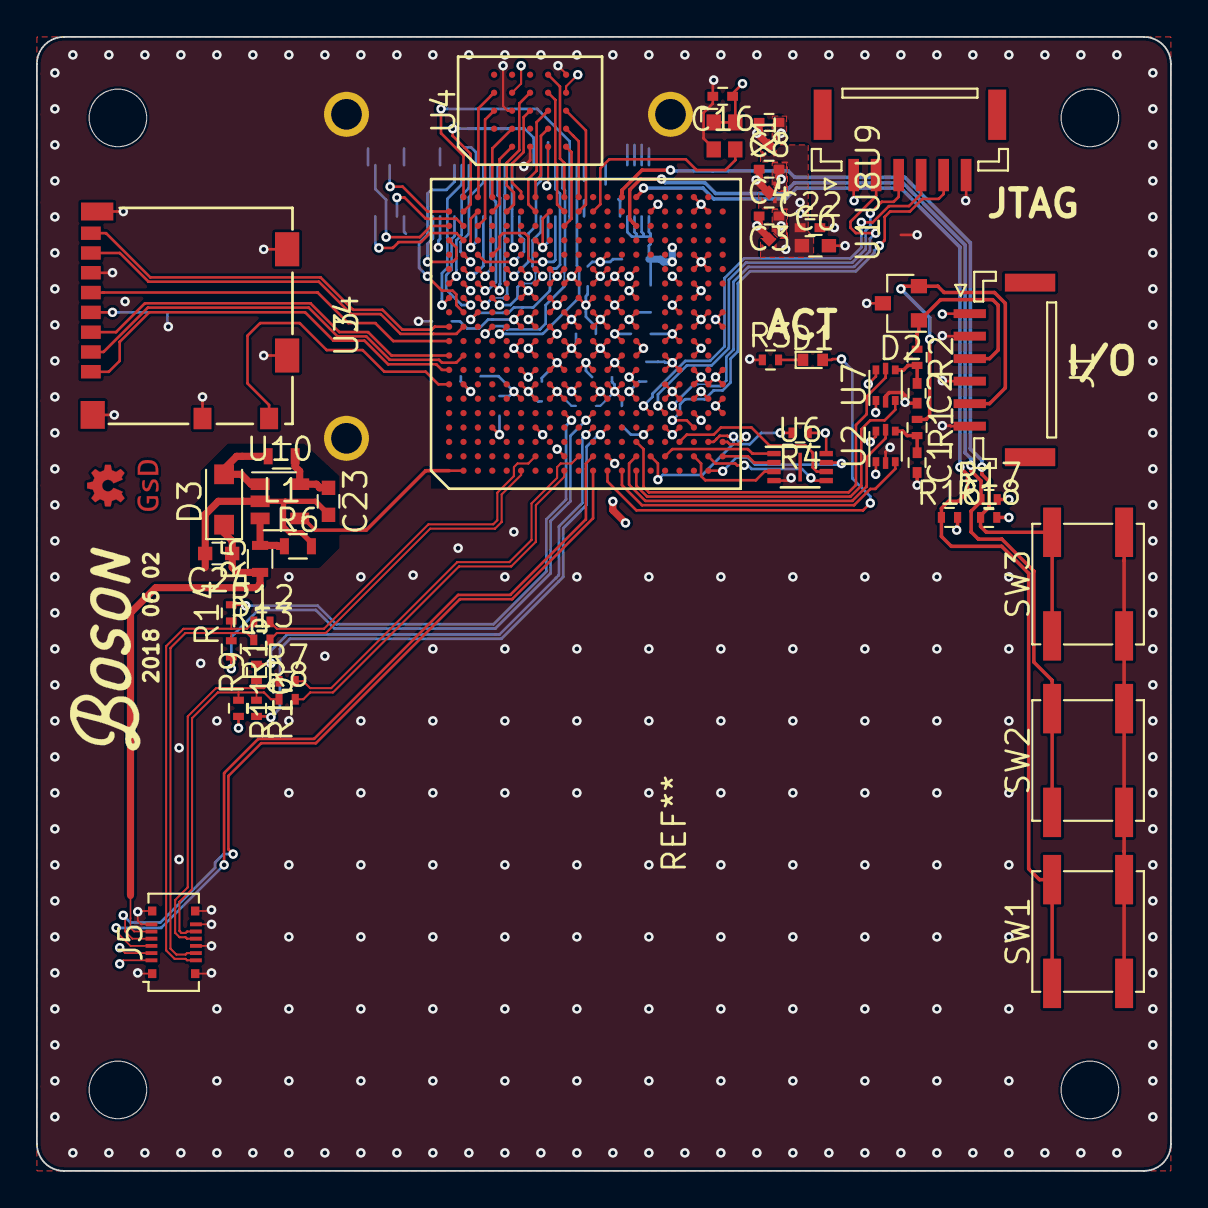
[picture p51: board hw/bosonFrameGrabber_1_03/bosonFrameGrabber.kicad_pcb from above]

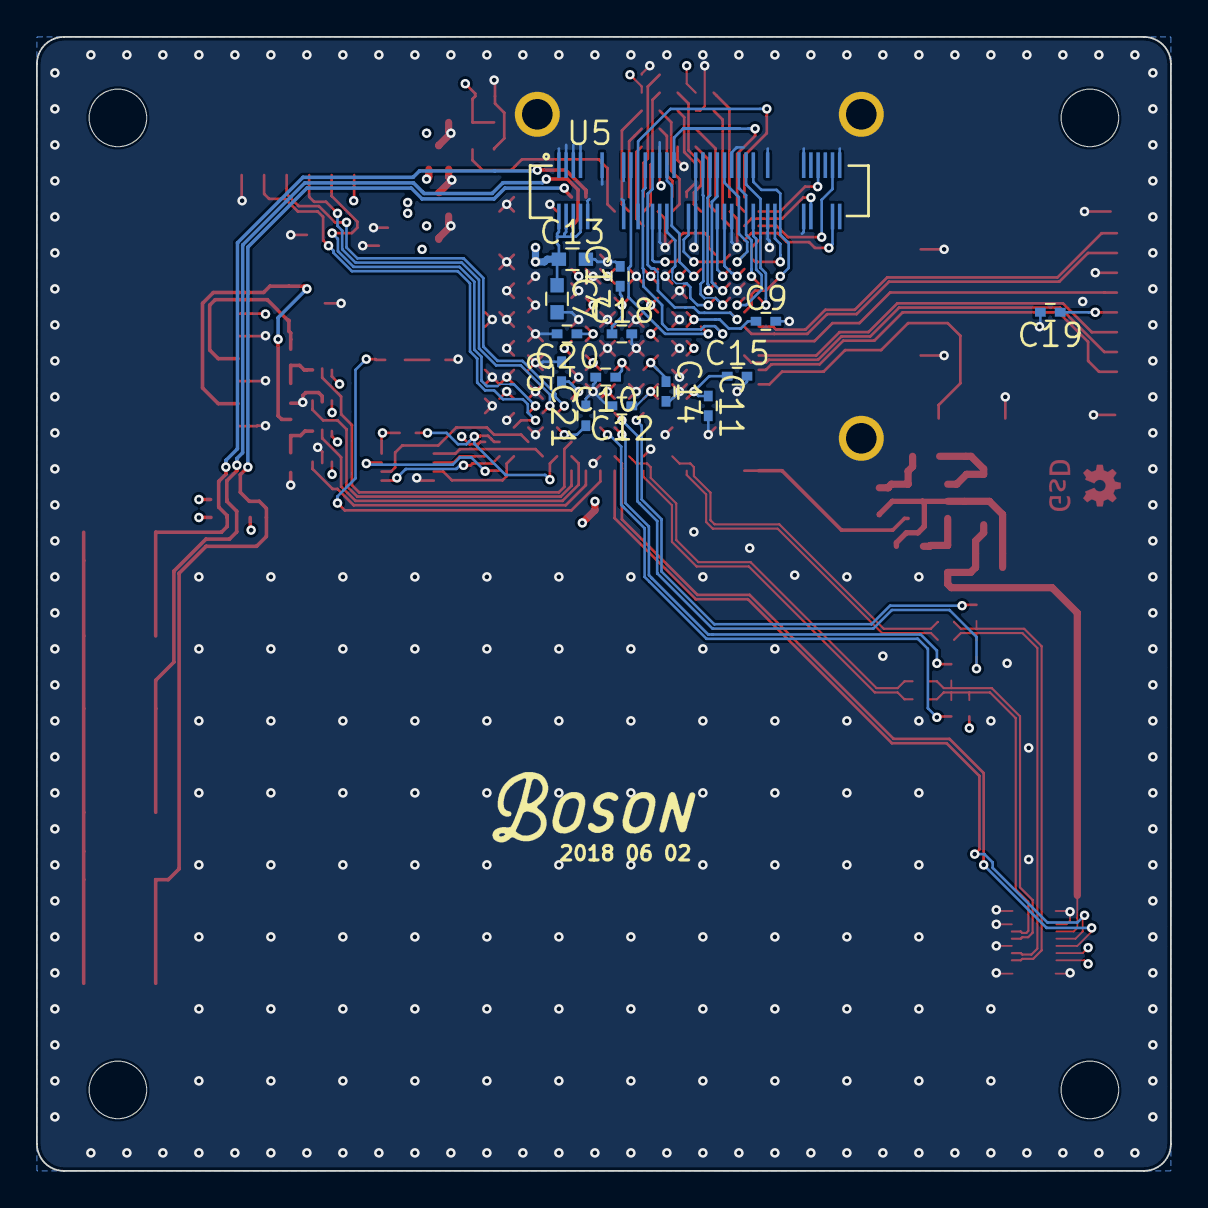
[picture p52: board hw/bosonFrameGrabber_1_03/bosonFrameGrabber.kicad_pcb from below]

Board: 4 copper layers, 63.0 x 63.0 mm, 64 parts (15 on the bottom side), 93 nets.

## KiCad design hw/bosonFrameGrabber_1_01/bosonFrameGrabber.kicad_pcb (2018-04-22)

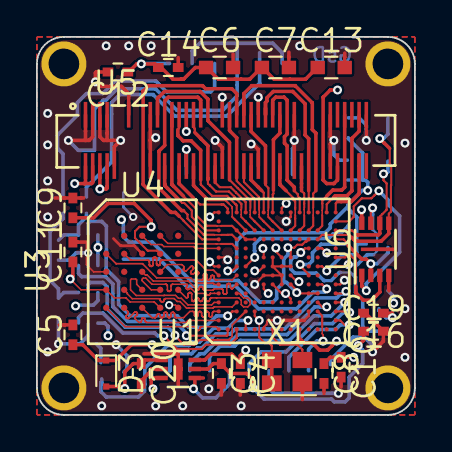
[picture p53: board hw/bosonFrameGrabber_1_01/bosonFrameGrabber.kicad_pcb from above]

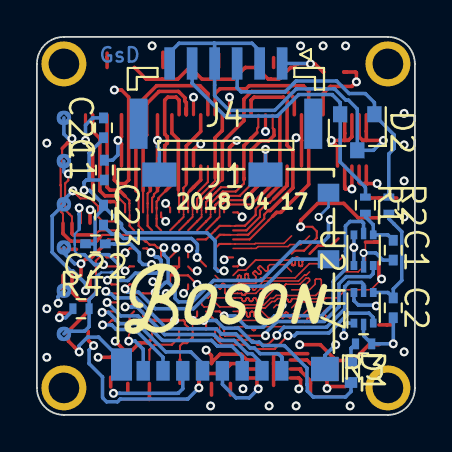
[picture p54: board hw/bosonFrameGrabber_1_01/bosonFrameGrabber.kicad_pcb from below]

Board: 4 copper layers, 21.0 x 21.0 mm, 38 parts (16 on the bottom side), 68 nets.

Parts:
C1, C2: 100pF; C_0402
C3, C4: 1uF; C_0402
C5: 100nF; C_0402
C6, C7, C13: 10uF; C_0603
C8, C9, C10, C11, C12, C14, C16, C17, C19, C20, C21, C22, C23: 100n; C_0402
D1: LED; LED_0402
D2: D_TVS_x2_AAC; SOT-23
D3: D_ALT; D_SC-80
J1: JST GH Series; JST_GH_BM06B-GHS-TBT_06x1.25mm_Straight
J4: MicroSD; 1040310811
R1, R2: 100R; R_0402
R3: R; R_0402
R4: 10k; R_0402
U1: MIC5370; DFN-6-1EP_2x2mm_Pitch0.5mm
U2, U7: SN74LVC1T45; SOT-666
U3: ICE40HX8K; csBGA_132
U4: S27KS0641; BGA_24
U5: Boson; DF40_80Pin
U6: AT25SF081; DFN-8-1EP_3x2mm_Pitch0.5mm
X1: ASDMB; Oscillator_SMD_SeikoEpson_SG210-4pin_2.5x2.0mm

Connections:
16MHZ_IN: U3.G1, X1.3
+1V2: C3.1, C17.1, C19.1, C21.1, C22.2, C23.1, U1.5, U3.C8, U3.F8, U3.G6, U3.H9, U3.J4, U3.J7, U3.M8
+1V8: C4.1, C8.1, C9.1, C10.1, C11.1, U1.6, U3.A8, U3.F6, U3.F9, U3.H14, U4.B4, U4.D1, U4.E4
+2V5: C5.1, D3.1, U3.A14
+3V3: C6.1, C7.1, C12.1, C13.1, C14.1, C16.1, C20.1, D3.2, J1.1, J4.4, R4.1, U1.1, U1.3, U1.4, U2.1, U2.6, U3.E3, U3.J6, U3.J9, U3.K1, U3.L5, U3.L11, U3.M5, U5.2, U5.4, U5.6, U5.8, U6.8, U7.1, U7.6, X1.1, X1.4
BOSON_CK: U3.G14, U5.55
BOSON_DATA0: U3.N14, U5.77
BOSON_DATA1: U3.K12, U5.62
BOSON_DATA2: U3.L14, U5.51
BOSON_DATA3: U3.J12, U5.56
BOSON_DATA4: U3.C14, U5.27
BOSON_DATA5: U3.B14, U5.28
BOSON_DATA6: U3.D12, U5.32
BOSON_DATA7: U3.E12, U5.31
BOSON_DATA8: U3.C12, U3.D11, U3.E11, U5.25
BOSON_DATA9: U3.G12, U5.46
BOSON_DATA10: U3.L12, U5.45
BOSON_DATA11: U3.F14, U5.48
BOSON_DATA12: U3.H12, U5.47
BOSON_DATA13: U3.E14, U5.41
BOSON_DATA14: U3.F12, U5.21
BOSON_DATA15: U3.D14, U5.38
BOSON_DATA_EN: U3.P14, U5.78
BOSON_HSYNC: U3.M12, U5.73
BOSON_RESET: U3.A12, U5.24
BOSON_RXD: U3.C11, U5.33
BOSON_TXD: U3.A11, U5.43
BOSON_VSYNC: U3.K14, U5.53
FPGA_RESET: R4.2, U3.L10
GND: C1.2, C2.2, C3.2, C4.2, C5.2, C6.2, C7.2, C8.2, C9.2, C10.2, C11.2, C12.2, C13.2, C14.2, C16.2, C17.2, C19.2, C20.2, C21.2, D2.3, J1.2, J1.4, J1.6, J4.6, J4.9, J4.11, R3.1, U1.2, U1.7, U2.2, U3.A9, U3.F1, U3.F7, U3.G7, U3.G8, U3.G9, U3.H6, U3.H7, U3.H8, U3.J8, U3.J14, U3.L3, U3.P6, U4.B3, U4.C1, U4.E5, U5.1, U5.3, U5.5, U5.7, U5.10, U5.13, U5.19, U5.20, U5.29, U5.30, U5.39, U5.40, U5.49, U5.50, U5.59, U5.60, U5.69, U5.70, U5.79, U6.4, U6.9, U7.2, X1.2
HYPERBUS_CK: U3.A7, U4.B2
HYPERBUS_CK#: U3.A6, U4.B1
HYPERBUS_CS#: U3.A10, U4.A3
HYPERBUS_DQ0: U3.A4, U4.D3
HYPERBUS_DQ1: U3.C4, U4.D2
HYPERBUS_DQ2: U3.C7, U4.C4
HYPERBUS_DQ3: U3.A5, U4.D4
HYPERBUS_DQ4: U3.C5, U4.D5
HYPERBUS_DQ5: U3.A3, U4.E3
HYPERBUS_DQ6: U3.A2, U4.E2
HYPERBUS_DQ7: U3.A1, U4.E1
HYPERBUS_RESET#: U3.C10, U4.A4
HYPERBUS_RWDS: U3.C6, U4.C3
IO_A: D2.2, J1.5, R1.1
IO_A_DIR: U2.5, U3.C3
IO_A_INTERNAL: U2.3, U3.B1
IO_B: D2.1, J1.3, R2.1
IO_B_DIR: U3.D3, U7.5
IO_B_INTERNAL: U3.C1, U7.3
LED_A: D1.2, U3.D1
unnamed: C1.1, R1.2, U2.4
unnamed: C2.1, R2.2, U7.4
unnamed: C22.1, U3.L7
unnamed: C23.2, U3.D8
unnamed: D1.1, R3.2
QSPI_D2: U3.P9, U6.3
QSPI_D3: U3.P8, U6.7
SD_CD: J4.10, U3.M6
SD_CK: J4.5, U3.P3
SD_CMD: J4.3, U3.P4
SD_DAT0: J4.7, U3.P2
SD_DAT1: J4.8, U3.M3
SD_DAT2: J4.1, U3.P5
SD_DAT3: J4.2, U3.M4
SPI_CONFIG_MISO: U3.P11, U6.2
SPI_CONFIG_MOSI: U3.M11, U6.5
SPI_CONFIG_SCK: U3.P12, U6.6
SPI_CONFIG_SS: U3.P13, U6.1

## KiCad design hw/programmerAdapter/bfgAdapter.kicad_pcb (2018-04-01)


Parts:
J1: Conn; FTSH-EDGE-20pin
J2: GS3
J4: Prog; PinSocket_1x06_P2.54mm_Vertical

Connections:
+5V: J1.1
/CS: J1.5, J2.1 (G1)
/DI: J1.6, J4.4
/DO: J1.3, J4.1
/GPIOH0: J1.12
/GPIOH1: J1.11
/GPIOH2: J1.14
/GPIOH3: J1.13
/GPIOH4: J1.16
/GPIOH5: J1.15
/GPIOH6: J1.18
/GPIOH7: J1.17
/GPIOH8: J1.20
/GPIOH9: J1.19
/GPIOL0: J1.8, J2.2 (G2), J2.3 (G3), J4.3
/GPIOL1: J1.7
/GPIOL2: J1.10, J4.5
/GPIOL3: J1.9, J4.6
/SK: J1.4, J4.2
GND: J1.2

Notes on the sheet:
STYLE ASYNC 245FIFO
~RXF
~TXE
~RD
~WR
~SIWU
ACBUS5
~OE
~PWRSAV
ACBUS8
ACBUS9
ASYNC Bit-bang
ACBUS0
~WRSTB
~RDSTB
ACBUS3
ACBUS6
SYNC Bit-bang
MPSSE
TCK/SK
TDI/DO
TDO/DI
TMS/CS
GPIOL0
GPIOL1
GPIOL2
GPIOL3
GPIOH0
GPIOH1
GPIOH2
GPIOH3
GPIOH4
GPIOH5
GPIOH6
GPIOH7
GPIOH8
GPIOH9
Fast Serial Interface
FSDI
FSCLK


Board: 2 copper layers, 18.4 x 21.0 mm, 3 parts (1 on the bottom side), 7 nets.

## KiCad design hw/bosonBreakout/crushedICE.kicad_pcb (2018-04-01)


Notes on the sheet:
To Add: FT230X Regulators LEDs SWD
Boson
FPGA HyperRAM
CMOS 16bit [27Mhz] 64Mbit/s
QSPI
SAMD51 SDMMC


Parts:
D1, D2, D3, D4, D5, D6: led green; LED_0805
J1, J2: Conn_02x12_Odd_Even
J5: Conn_02x05_Odd_Even; Pin_Header_Straight_2x05_Pitch2.54mm
J7: Conn_01x10; Pin_Header_Straight_1x10_Pitch2.54mm
RN1, RN2: R_Pack04; R_Array_Convex_4x0603

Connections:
+1V2: J7.5; also elsewhere on the board
+1V8: J7.4; also elsewhere on the board
+2V5: J7.3; also elsewhere on the board
+3V3: J7.2, RN1.5 (R4.2), RN1.6 (R3.2), RN1.7 (R2.2), RN1.8 (R1.2), RN2.5 (R4.2), RN2.6 (R3.2), RN2.7 (R2.2), RN2.8 (R1.2); also elsewhere on the board
+5V: J7.1; also elsewhere on the board
BOSON_RXD: J1.2; also elsewhere on the board
BOSON_TXD: J1.1; also elsewhere on the board
CAM_CLK: J1.21; also elsewhere on the board
CAM_D0: J1.3; also elsewhere on the board
CAM_D1: J1.4; also elsewhere on the board
CAM_D2: J1.5; also elsewhere on the board
CAM_D3: J1.6; also elsewhere on the board
CAM_D4: J1.7; also elsewhere on the board
CAM_D5: J1.8; also elsewhere on the board
CAM_D6: J1.9; also elsewhere on the board
CAM_D7: J1.10; also elsewhere on the board
CAM_D8: J1.11; also elsewhere on the board
CAM_D9: J1.12; also elsewhere on the board
CAM_D10: J1.13; also elsewhere on the board
CAM_D11: J1.14; also elsewhere on the board
CAM_D12: J1.15; also elsewhere on the board
CAM_D13: J1.16; also elsewhere on the board
CAM_D14: J1.17; also elsewhere on the board
CAM_D15: J1.18; also elsewhere on the board
CAM_HSYNC: J1.24; also elsewhere on the board
CAM_VALID: J1.22; also elsewhere on the board
CAM_VSYNC: J1.23; also elsewhere on the board
CDONE/IO_C: J2.22; also elsewhere on the board
DEBUG_TX: J2.24; also elsewhere on the board
FPGA_CS: J2.20; also elsewhere on the board
GND: J1.19, J1.20, J2.1, J2.2, J2.16, J5.10, J7.6, J7.7, J7.8, J7.9, J7.10; also elsewhere on the board
HB_CK: J2.11; also elsewhere on the board
HB_CK#: J2.12; also elsewhere on the board
HB_CS#: J2.14; also elsewhere on the board
HB_DQ0: J2.3; also elsewhere on the board
HB_DQ1: J2.4; also elsewhere on the board
HB_DQ2: J2.5; also elsewhere on the board
HB_DQ3: J2.6; also elsewhere on the board
HB_DQ4: J2.7; also elsewhere on the board
HB_DQ5: J2.8; also elsewhere on the board
HB_DQ6: J2.9; also elsewhere on the board
HB_DQ7: J2.10; also elsewhere on the board
HB_RESET#: J2.13; also elsewhere on the board
HB_RWDS: J2.15; also elsewhere on the board
LED_A: D1.1 (K); also elsewhere on the board
LED_B: D2.1 (K); also elsewhere on the board
LED_C: D3.1 (K); also elsewhere on the board
LED_D: D4.1 (K); also elsewhere on the board
LED_E: D5.1 (K); also elsewhere on the board
LED_F: D6.1 (K); also elsewhere on the board
unnamed: D1.2 (A), RN1.1 (R1.1)
unnamed: D2.2 (A), RN1.2 (R2.1)
unnamed: D3.2 (A), RN1.3 (R3.1)
unnamed: D4.2 (A), RN2.1 (R1.1)
unnamed: D5.2 (A), RN2.2 (R2.1)
unnamed: D6.2 (A), RN2.3 (R3.1)
SDMMC_SEL: J5.9; also elsewhere on the board
SD_CLK: J5.6; also elsewhere on the board
SD_CMD: J5.5; also elsewhere on the board
SD_CMD/QSPI_D0: J2.17; also elsewhere on the board
SD_D0: J5.7; also elsewhere on the board
SD_D1: J5.8; also elsewhere on the board
SD_D2: J5.3; also elsewhere on the board
SD_D3: J5.4; also elsewhere on the board
SD_DAT0/QSPI_D1: J2.19; also elsewhere on the board
SD_DAT1/QSPI_D2: J2.21; also elsewhere on the board
SD_DAT2/QSPI_D3: J2.23; also elsewhere on the board
SD_DAT3/QSPI_SCK: J2.18; also elsewhere on the board
USB_DATA_N: J5.1; also elsewhere on the board
USB_DATA_P: J5.2; also elsewhere on the board


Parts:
U4: Boson; DF40_80Pin

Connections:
+3V3: U4.2 (3V3), U4.4 (3V3), U4.6 (3V3), U4.8 (3V3); also elsewhere on the board
BOSON_RESET: U4.24 (RESET)
BOSON_RXD: U4.33 (UART_APB_SIN[GPIO_14]); also elsewhere on the board
BOSON_TXD: U4.43 (UART_APB_SOUT[GPIO_15]); also elsewhere on the board
CAM_CLK: U4.55 (CMOS_PIXCLK[GPIO_29]); also elsewhere on the board
CAM_D0: U4.77 (CMOS_DATA00[GPIO_36]); also elsewhere on the board
CAM_D1: U4.62 (CMOS_DATA01[GPIO_37]); also elsewhere on the board
CAM_D2: U4.51 (CMOS_DATA02[GPIO_38]); also elsewhere on the board
CAM_D3: U4.56 (CMOS_DATA03[GPIO_39]); also elsewhere on the board
CAM_D4: U4.27 (CMOS_DATA04[GPIO_40]); also elsewhere on the board
CAM_D5: U4.28 (CMOS_DATA05[GPIO_41]); also elsewhere on the board
CAM_D6: U4.32 (CMOS_DATA06[GPIO_42]); also elsewhere on the board
CAM_D7: U4.31 (CMOS_DATA07[GPIO_43]); also elsewhere on the board
CAM_D8: U4.25 (CMOS_DATA08[GPIO_44]); also elsewhere on the board
CAM_D9: U4.46 (CMOS_DATA09[GPIO_45]); also elsewhere on the board
CAM_D10: U4.45 (CMOS_DATA10[GPIO_46]); also elsewhere on the board
CAM_D11: U4.48 (CMOS_DATA11[GPIO_47]); also elsewhere on the board
CAM_D12: U4.47 (CMOS_DATA12[GPIO_48]); also elsewhere on the board
CAM_D13: U4.41 (CMOS_DATA13[GPIO_16]); also elsewhere on the board
CAM_D14: U4.21 (CMOS_DATA14[GPIO_17]); also elsewhere on the board
CAM_D15: U4.38 (CMOS_DATA15[GPIO_18]); also elsewhere on the board
CAM_HSYNC: U4.73 (CMOS_HSYNC[GPIO_31]); also elsewhere on the board
CAM_VALID: U4.78 (CMOS_DATA_EN[GPIO_32]); also elsewhere on the board
CAM_VSYNC: U4.53 (CMOS_VSYNC[GPIO_30]); also elsewhere on the board
EXT_SYNC: U4.72 (EXT_SYNC)
GND: U4.1 (DGND), U4.3 (DGND), U4.5 (DGND), U4.7 (DGND), U4.10 (DGND), U4.13 (DGND), U4.19 (DGND), U4.20 (DGND), U4.29 (DGND), U4.30 (DGND), U4.39 (DGND), U4.40 (DGND), U4.49 (DGND), U4.50 (DGND), U4.59 (DGND), U4.60 (DGND), U4.69 (DGND), U4.70 (DGND), U4.79 (DGND); also elsewhere on the board


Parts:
C24, C25, C26, C27, C28, C29, C30, C31: 100n; C_0603
U1: ICE5LP4K-SG48; QFN-48-1EP_7x7mm_Pitch0.5mm
U2: S27KS0641; BGA_24

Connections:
+1V2: C25.1, C27.1, C29.1, U1.5 (VCC), U1.29 (VCCPLL), U1.30 (VCC); also elsewhere on the board
+1V8: C24.1, C26.1, C28.1, C30.1, U1.1 (VCCIO_2), U1.22 (VCCIO_1_SPI), U1.33 (VCCIO_0), U2.B4 (VCC), U2.D1 (VCCQ), U2.E4 (VCCQ); also elsewhere on the board
+2V5: C31.1, U1.24 (VPP_2V5); also elsewhere on the board
CAM_CLK: U1.45 (IOB_5b); also elsewhere on the board
CAM_D0: U1.43 (IOT_49a); also elsewhere on the board
CAM_D1: U1.44 (IOB_3b); also elsewhere on the board
CAM_D2: U1.47 (IOB_2a); also elsewhere on the board
CAM_D3: U1.46 (IOB_0a); also elsewhere on the board
CAM_D4: U1.11 (IOB_20a); also elsewhere on the board
CAM_D5: U1.13 (IOB_24a); also elsewhere on the board
CAM_D6: U1.12 (IOB_22a); also elsewhere on the board
CAM_D7: U1.10 (IOB_18a); also elsewhere on the board
CAM_D8: U1.18 (IOB_31b); also elsewhere on the board
CAM_D9: U1.3 (IOB_9b); also elsewhere on the board
CAM_D10: U1.4 (IOB_8a); also elsewhere on the board
CAM_D11: U1.2 (IOB_6a); also elsewhere on the board
CAM_D12: U1.48 (IOB_4a); also elsewhere on the board
CAM_D13: U1.6 (IOB_13b); also elsewhere on the board
CAM_D14: U1.19 (IOB_29b); also elsewhere on the board
CAM_D15: U1.9 (IOB_16b); also elsewhere on the board
CAM_VALID: U1.42 (IOT_51a); also elsewhere on the board
CDONE/IO_C: U1.7 (CDONE); also elsewhere on the board
FPGA_CS: U1.16 (IOB_35b_SPI_CSN); also elsewhere on the board
FPGA_RST: U1.8 (creset_b); also elsewhere on the board
GND: C24.2, C25.2, C26.2, C27.2, C28.2, C29.2, C30.2, C31.2, U1.49 (GND), U2.B3 (VSS), U2.C1 (VSSQ), U2.E5 (VSSQ); also elsewhere on the board
HB_CK: U1.25 (IOT_36b), U2.B2 (CK); also elsewhere on the board
HB_CK#: U1.23 (IOT_37a), U2.B1 (CK#); also elsewhere on the board
HB_CS#: U1.26 (IOT_39a), U2.A3 (CS#); also elsewhere on the board
HB_DQ0: U1.32 (IOT_43a), U2.D3 (DQ0); also elsewhere on the board
HB_DQ1: U1.28 (IOT_41a), U2.D2 (DQ1); also elsewhere on the board
HB_DQ2: U1.37 (IOT_45a), U2.C4 (DQ2); also elsewhere on the board
HB_DQ3: U1.36 (IOT_48b), U2.D4 (DQ3); also elsewhere on the board
HB_DQ4: U1.38 (IOT_50b), U2.D5 (DQ4); also elsewhere on the board
HB_DQ5: U1.34 (IOT_44b), U2.E3 (DQ5); also elsewhere on the board
HB_DQ6: U1.31 (IOT_42b), U2.E2 (DQ6); also elsewhere on the board
HB_DQ7: U1.27 (IOT_38b), U2.E1 (DQ7); also elsewhere on the board
HB_RESET#: U2.A4 (RESET#); also elsewhere on the board
HB_RWDS: U1.35 (IOT_46b), U2.C3 (RWDS); also elsewhere on the board
LED_A: U1.39 (rgb2); also elsewhere on the board
LED_B: U1.40 (rgb1); also elsewhere on the board
LED_C: U1.41 (rgb0); also elsewhere on the board
SD_CMD/QSPI_D0: U1.17 (IOB_33b_SPI_SI); also elsewhere on the board
SD_DAT0/QSPI_D1: U1.14 (IOB_32a_SPI_SO); also elsewhere on the board
SD_DAT1/QSPI_D2: U1.20 (IOB_25b_G3); also elsewhere on the board
SD_DAT2/QSPI_D3: U1.21 (IOB_23b); also elsewhere on the board
SD_DAT3/QSPI_SCK: U1.15 (IOB_34a_SPI_SCK); also elsewhere on the board


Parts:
C14: 1uF; C_0603
C15: 10n; C_0603
C16, C17: 26pF; C_0603
C18, C19, C20, C21, C22, C23: 100n; C_0603
J3: MicroSD; SD_holder_472190001
J4: USB_OTG; USB_Micro-B_10103594-0001LF
J6: cortex SWD; CORTEX_SWD
JP1: Jumper_NC_Small; R_0201_NoSilk
R12: 1K; R_0603
U5: ATSAMD51G19A; QFN-48-1EP_7x7mm_Pitch0.5mm
U10: TXS02612; QFN-24-1EP_4x4mm_Pitch0.5mm
Y1: 16MHz; Crystal_SMD_3225-4pin_3.2x2.5mm

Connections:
+1V8: C20.1, C21.1, C22.1, C23.1, J6.1, R12.1, U5.6 (VDDANA~), U5.17 (VDDIO~), U5.36 (VDDIO~), U5.44 (VDDIO~), U10.5 (VCCA); also elsewhere on the board
+3V3: C18.1, C19.1, J3.4, U10.17 (VCCB1), U10.21 (VCCB0); also elsewhere on the board
+5V: C15.1, JP1.2; also elsewhere on the board
/Microcontroller/VUSB: J4.1 (VBUS), JP1.1
/Microcontroller/XOSC1_XIN: C16.2, U5.23 (PA14~), Y1.1
/Microcontroller/XOSC1_XOUT: C17.2, U5.24 (PA15~), Y1.3
BOSON_RXD: U5.1 (PA00); also elsewhere on the board
BOSON_TXD: U5.2 (PA01~); also elsewhere on the board
CAM_VALID: U5.3 (PA02~); also elsewhere on the board
CDONE/IO_C: U5.29 (PA20~); also elsewhere on the board
DEBUG_TX: U5.32 (PA23~); also elsewhere on the board
FPGA_CS: U5.28 (PA19~); also elsewhere on the board
FPGA_RST: U5.26 (PA17~); also elsewhere on the board
GND: C14.2, C15.2, C16.1, C17.1, C18.2, C19.2, C20.2, C21.2, C22.2, C23.2, J3.6, J3.9, J4.5 (GND), J4.6 (Shield), J6.3, J6.5, U5.5 (GND~), U5.18 (GND~), U5.35 (GND~), U5.42 (GND), U5.49 (GND), U10.2 (GND), U10.11 (GND), Y1.2, Y1.4; also elsewhere on the board
LED_D: U5.47 (PB02~); also elsewhere on the board
LED_E: U5.48 (PB03~); also elsewhere on the board
LED_F: U5.7 (PB08~); also elsewhere on the board
unnamed: C14.1, U5.41 (VDDCORE~)
SAM_RST: J6.10, U5.40 (~RESET)
SAM_SWCLK: J6.4, R12.2, U5.45 (PA30~)
SAM_SWDIO: J6.2, U5.46 (PA31~)
SDMMC_SEL: U5.12 (PA07~), U10.24 (SEL); also elsewhere on the board
SD_CK/QSPI_CS: U5.20 (PB11~), U5.25 (PA16~), U10.9 (CLKA)
SD_CLK: J3.5, U10.19 (CLKB0); also elsewhere on the board
SD_CMD: J3.3, U10.20 (CMDB0); also elsewhere on the board
SD_CMD/QSPI_D0: U5.13 (PA08~), U10.4 (CMDA); also elsewhere on the board
SD_D0: J3.7, U10.18 (DAT0B0); also elsewhere on the board
SD_D1: J3.8, U10.16 (DAT1B0); also elsewhere on the board
SD_D2: J3.1, U10.23 (DAT2B0); also elsewhere on the board
SD_D3: J3.2, U10.22 (DAT3B0); also elsewhere on the board
SD_DAT0/QSPI_D1: U5.14 (PA09~), U10.6 (DAT0A); also elsewhere on the board
SD_DAT1/QSPI_D2: U5.15 (PA10~), U10.7 (DAT1A); also elsewhere on the board
SD_DAT2/QSPI_D3: U5.16 (PA11~), U10.1 (DAT2A); also elsewhere on the board
SD_DAT3/QSPI_SCK: U5.19 (PB10~), U10.3 (DAT3A); also elsewhere on the board
USB_DATA_N: J4.2 (D-), U5.33 (PA24~); also elsewhere on the board
USB_DATA_P: J4.3 (D+), U5.34 (PA25~); also elsewhere on the board

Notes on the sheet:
DAT2 DAT3 CMD VDD CLK VSS DAT0 DAT1 GND
PMUX_A (EIC_2)
PMUX_D (SERCOM1_0) [USART_TX]
PMUX_D (SERCOM1_1) [USART_RX]
PMUX_N (CCL_IN0)
PMUX_N (CCL_OUT0)
GPIO
PMUX_H (USB_DM)
PMUX_H (USB_DP)
PMUX{H (QSPI_D0), I (SD_CMD)}
PMUX{H (QSPI_D1), I (SD_D0)}
PMUX{H (QSPI_D2), I (SD_D1)}
PMUX{H (QSPI_D3), I (SD_D2)}
PMUX{H (QSPI_SCK), I (SD_D3)}
PMUX{H (QSPI_CS), I (SD_CK)}
Note: Using CCL I/O 0,1 to gate QSPI_CS from SD_CK
PMUX_D (SERCOM5_0) [USART_TX]
Place Close To IC power pins


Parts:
C1: 10uF; C_0805
C2, C3, C13: 100n; C_0603
C4, C5, C6: 22nF; C_0603
C7, C8: 22uF; C_0805
C9, C10, C11, C12: 1uF; C_0603
L1: 4.7uH; Inductor_Taiyo-Yuden_MD-3030
R2: 2.0K; R_0603
R3, R5, R7, R9, R11: 10K; R_0603
R4: 15K; R_0603
R6: 17.8K; R_0603
R8: 8.0K; R_0603
R10: 23K; R_0603
U6, U7: SC560A; MLPQ-UT8
U8: TS30011; QFN-16-1EP_3x3mm_Pitch0.5mm_ThermalVias

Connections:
+1V2: C10.1, R2.2, U6.3 (OUTA); also elsewhere on the board
+1V8: C11.1, R8.2, U6.1 (OUTB), U7.6 (EN); also elsewhere on the board
+2V5: C12.1, R4.2, U7.3 (OUTA); also elsewhere on the board
+3V3: C7.1, C8.1, L1.1, R6.1; also elsewhere on the board
+5V: C1.1, C2.1, C3.1, C13.1, U6.2 (VIN), U6.6 (EN), U7.2 (VIN), U8.2 (VCC), U8.3 (VCC), U8.11 (VCC); also elsewhere on the board
GND: C1.2, C2.2, C3.2, C4.2, C5.2, C7.2, C8.2, C9.2, C10.2, C11.2, C12.2, C13.2, R3.2, R5.2, R7.2, R9.2, R11.2, U6.5 (GND), U7.5 (GND), U8.4 (GND), U8.14 (PGND), U8.15 (PGND), U8.17 (PAD); also elsewhere on the board
unnamed: C4.1, U6.7 (BYP)
unnamed: C5.1, U7.7 (BYP)
unnamed: C6.1, L1.2, U8.1 (VSW), U8.12 (VSW), U8.13 (VSW), U8.16 (VSW)
unnamed: C6.2, U8.10 (BST)
unnamed: C9.1, R10.2, U7.1 (OUTB)
unnamed: R2.1, R3.1, U6.4 (FBA)
unnamed: R4.1, R5.1, U7.4 (FBA)
unnamed: R6.2, R7.1, U8.5 (FB)
unnamed: R8.1, R9.1, U6.8 (FBB)
unnamed: R10.1, R11.1, U7.8 (FBB)

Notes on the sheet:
3V3 [BOSON, SDMMC]
2V5 [FPGA Programming]
1V8 [FPGA + MCU]
1V2 [FPGA PLL]
Boson Max 520mA (during FFC)
Power up sequence. 1.2V -> 1.8V - >2.5V
EN has internal Pullup
Vout = 0.9 * ( 1 + (R_top/R_bot))
TS30011 1A DCDC supply
Vout = 1.0 * ( 1 + (R_top / R_bot))


Board: 4 copper layers, 100.0 x 50.0 mm, 68 parts (0 on the bottom side), 89 nets.

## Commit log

2018-04-01 Initial Commit of 3 projects.
    [1040310811.stp, ASDMB.STEP, ASPI-3012S.STEP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]
2018-04-22 Update PCB with new footprint. Code project for bosonBreakout. (samd51) Simulation code for Verilog HyperRam module.
    [1040310811.stp, ASDMB.STEP, BM06B-GHS-TBT.STEP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]
2018-05-12 Updated SPI driver with a simple DMA.
2018-07-15 Update hw. Upload of hw 1_02 and hw 1_03
    [1040310811.stp, 5035481220.stp, ASDMB.STEP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]
2018-07-15 Actually removed old legacy fw projects.
    [s27ks0641.sdf]
2018-07-22 Added new module. Camera Capture Controller. Started adding functionality to the CCC.
2018-08-12 Create and test a hyperram module. add basic sim folder for hyperram
    [s27ks0641.sdf]
2018-08-28 Reset wb_streamer to "stock". STill not running when it is enabled. Current code with 2 "dummy rams" operates as expected. Attempting to tweak "arbiter" based on some undefined values in sim
2018-09-04 Added "ccc" Camera Capture Controller module Reverted uart to use Lite version Updates to PLL lock/reset timeout Revert DC fifo in stream_dual_clock to a generic version. Revert changes to wb_streame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
2018-09-24 Update to low level SD drivers of FatFS to begin testing multi block read/writes to the SD interface. Added Simple looping capture function to start testing a simple intervalometer mode.
2018-09-25 Updates to project documentation.
    [bfgAdapter.stp, bosonFrameGrabber.kicad_pcb, fileFPGA.sch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]
2018-10-01 Changes to support the 640 camera!
2018-10-01 Tidy up of main file. Enable wiring to SD controller again. disable SUMP2 integrated debugger.
2018-10-02 Add Generated output files. Mistakenly not included due to .gitignore settings.
    [bosonFrameGrabber.csv, bosonFrameGrabber_1_02_bom.csv]
2018-10-07 Updates to RTL to support a software reset. Updates to bootloader. Altered activation bits of SPIMEMIO Added uart files for debug. Switched to 64kb erase size. Currently erases and updates flash, but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
2018-10-08 Add very basic hardware SPI output support to SPIMEMIO. Writing to [0x2] will transmit that data with the MEMIO interface.
2018-10-08 Updates to the simple hacked together HW SPI. Test code added to the firmware
2018-10-09 Updates to hardware SPI in SPIMEMIO. Support for 32bit output Supprot for hardware endian swap
2018-10-09 Bootleader Updates. Support 32bit writes and endian swap Rework entire bootloader process to use HW SPI Poll device for erase times Poll device for program times.
2018-10-14 Updates to bootloader. Set LED once done. Hard-code page count to program entire 8Mb of FLASH. Trivial cmp between FLASH and file CRC to determine if update is required. Set SP in start.s to end of R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
2018-10-17 Update bootloader to provide visual feedback. Correct register values. Fix issue with frame_len register not reseting. pass enable signal back out into a register.
2018-10-18 Add sw_reset to wb_streamer, Add a frame counter. Automatically use detected image size.
2018-10-26 Updates with current changes. Still working on updating DRAM driver.
2018-10-28 Updates to hyperRAM to better support Low latency mode. Issues with variable latency. Sometimes the read values were wrong. Currently gating RWDS stobing based on cycle count.
2018-11-25 Started testing CRC32 implementation in bootloader.
    [bosonFrameGrabber.csv, crushedICE.csv]
2018-11-29 Bootloader updates. CRC32 now works. Need to work a little more on user feedback using the single LED.
2021-11-22 Remove old firmware/gateware
    [s27ks0641.sdf]

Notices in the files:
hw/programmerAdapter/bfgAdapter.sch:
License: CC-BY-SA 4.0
